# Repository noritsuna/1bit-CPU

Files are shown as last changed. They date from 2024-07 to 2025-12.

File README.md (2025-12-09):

# 1bit CPU made with ASIC (ISHI-Kai's OpenMPW PTC06-1)
[naoto64氏の1bit-CPU](https://naoto64.github.io/1bit-CPU/)を[ISHI会版OpenMPW PTC06-1](https://ishi-kai.org/openmpw/shuttle/ptc06/2024/07/06/shuttle_ISHI-Kai_OpenMPW-PTC06-1_start.html)を利用して、ASIC化しました！  
サイズは、280um x 65um くらいとなりました。元の基板が85mm x 70mmですのでおよそ36万分の1に縮小できました！  

 1bit-CPU
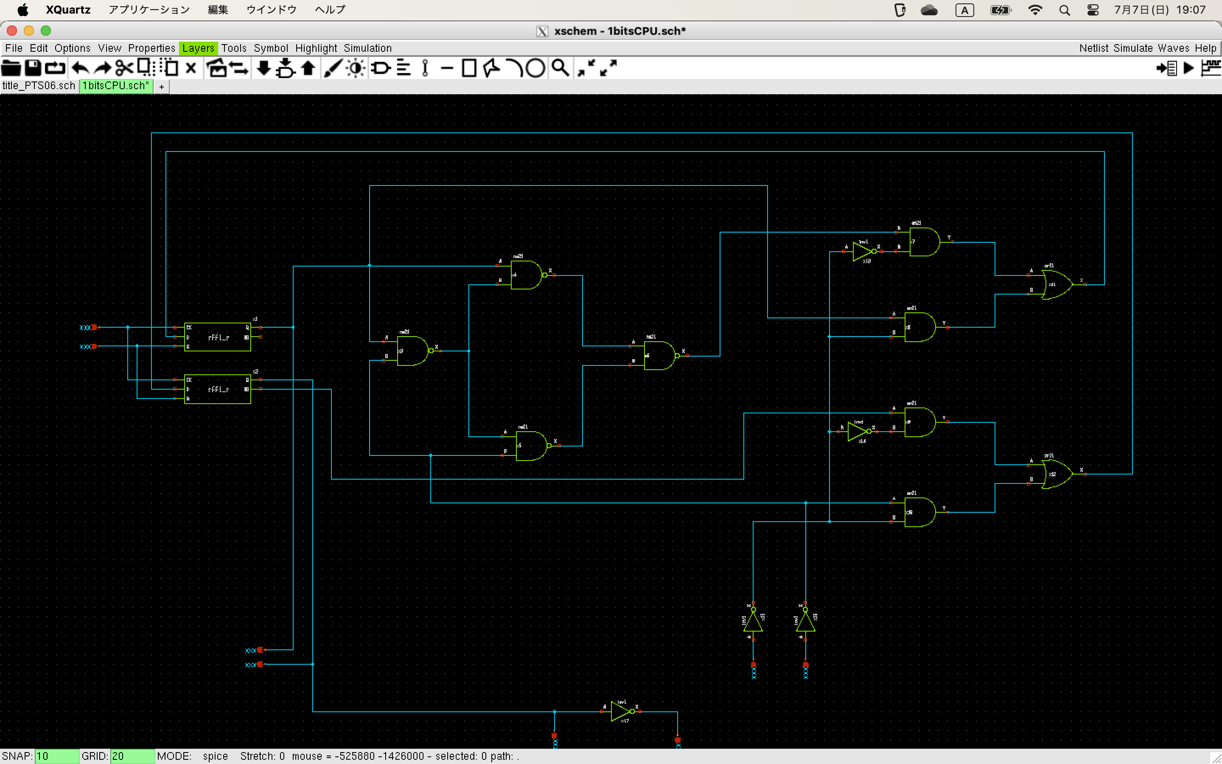
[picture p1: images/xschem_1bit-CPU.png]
1bit-CPUの回路図
 
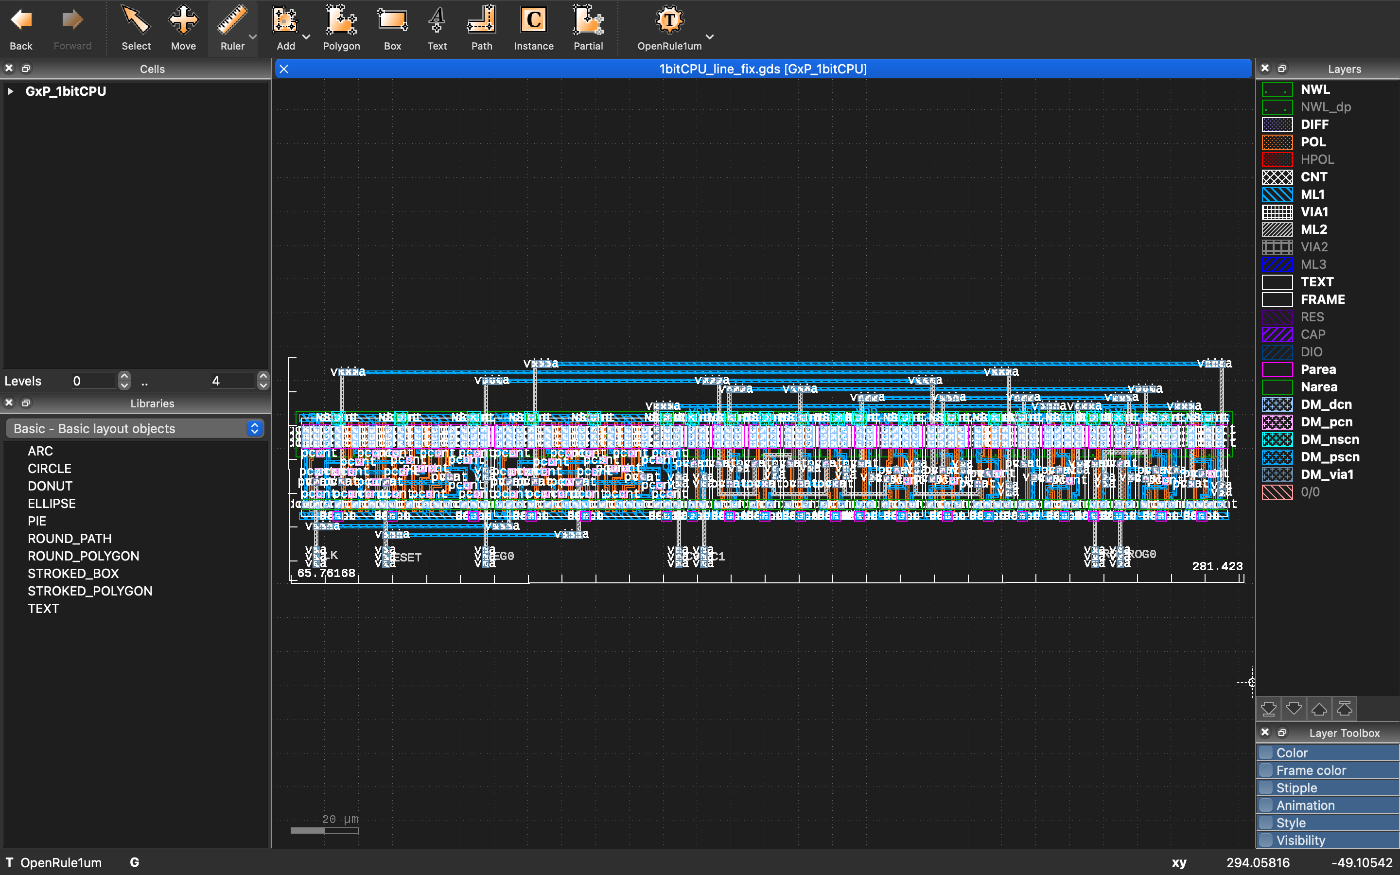
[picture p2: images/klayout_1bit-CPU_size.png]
 

# 論理回路化
まずは、74HC series logic IC部分を論理回路に起こし直して、シミュレーションを行いました。  
シミュレーションには[logicsim](http://www.cburch.com/logisim/)を利用しています。  

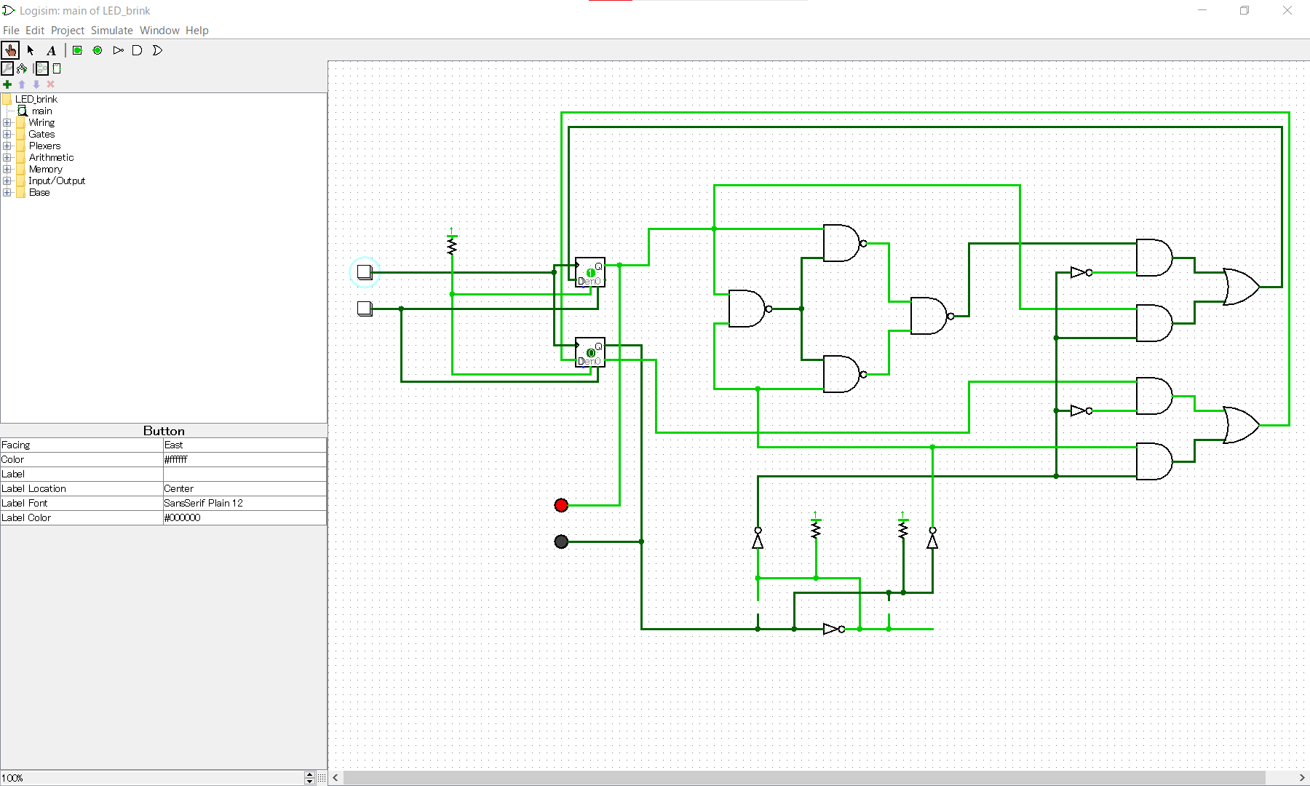
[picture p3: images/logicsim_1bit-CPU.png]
1bit-CPUのシミュレーション回路
 

## 各種回路
本家のサンプル回路をシミュレーションしました。  

-[LED点滅回路](logicsim/LED_brink.circ)
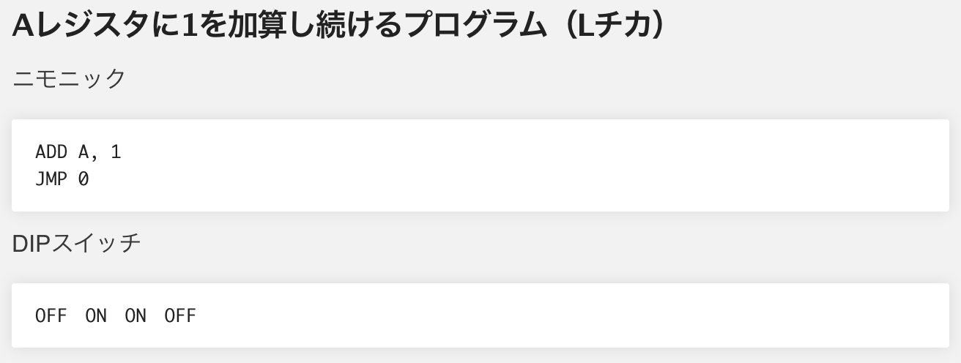
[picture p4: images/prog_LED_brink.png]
LED点滅回路
 
-[LED点灯回路](logicsim/LED_flash.circ)
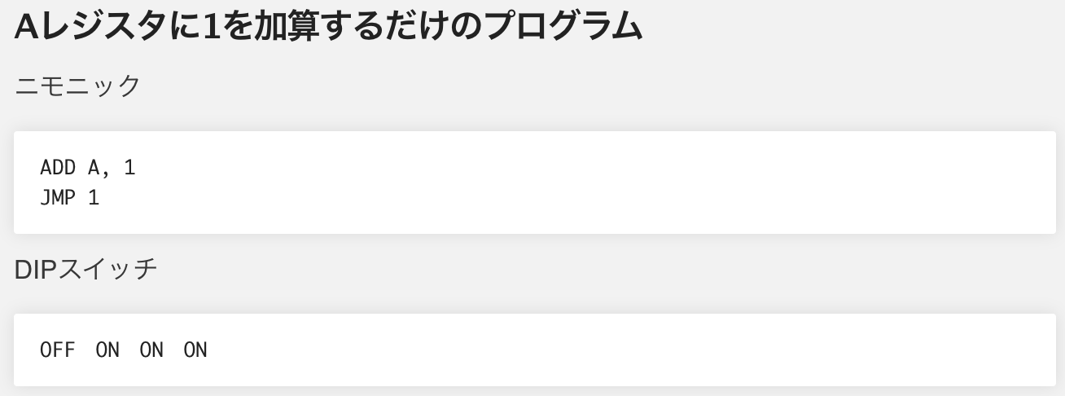
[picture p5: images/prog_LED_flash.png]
LED点灯回路
 
-[NOP回路](logicsim/NOP.circ)
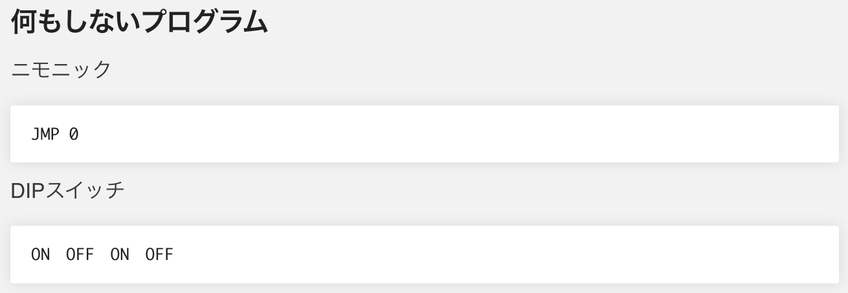
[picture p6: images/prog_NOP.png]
NOP回路
 

# AISC化
ここから、ASICにするための設計を行なっていきます。  

## 回路図
まずは、回路図を書きます。とは言っても、シミュレーション時に回路としては完成しているので、それをxschemで書き直しただけです。  

-[回路図](xschem/1bit-CPU.sch)
 1bit-CPUの回路図

## レイアウト
続いて、論理回路のレイアウトをします。  
論理回路は実際には、P-FETやN-FETを組み合わせて機能が実現されています。  

 NAND回路のFETによる実装例

もちろん、P-FETやN-FETを組み合わせて、自分で論理回路のレイアウトをしても良いのですが、通常スタセル（スタンダードセル）という物が用意されています。  
要は、P-FETやN-FETを組み合わせて作られている論理回路ライブラリです。3つ目が拡大図でP-FETとN-FETで構成されているのが確認できるかと思います。  

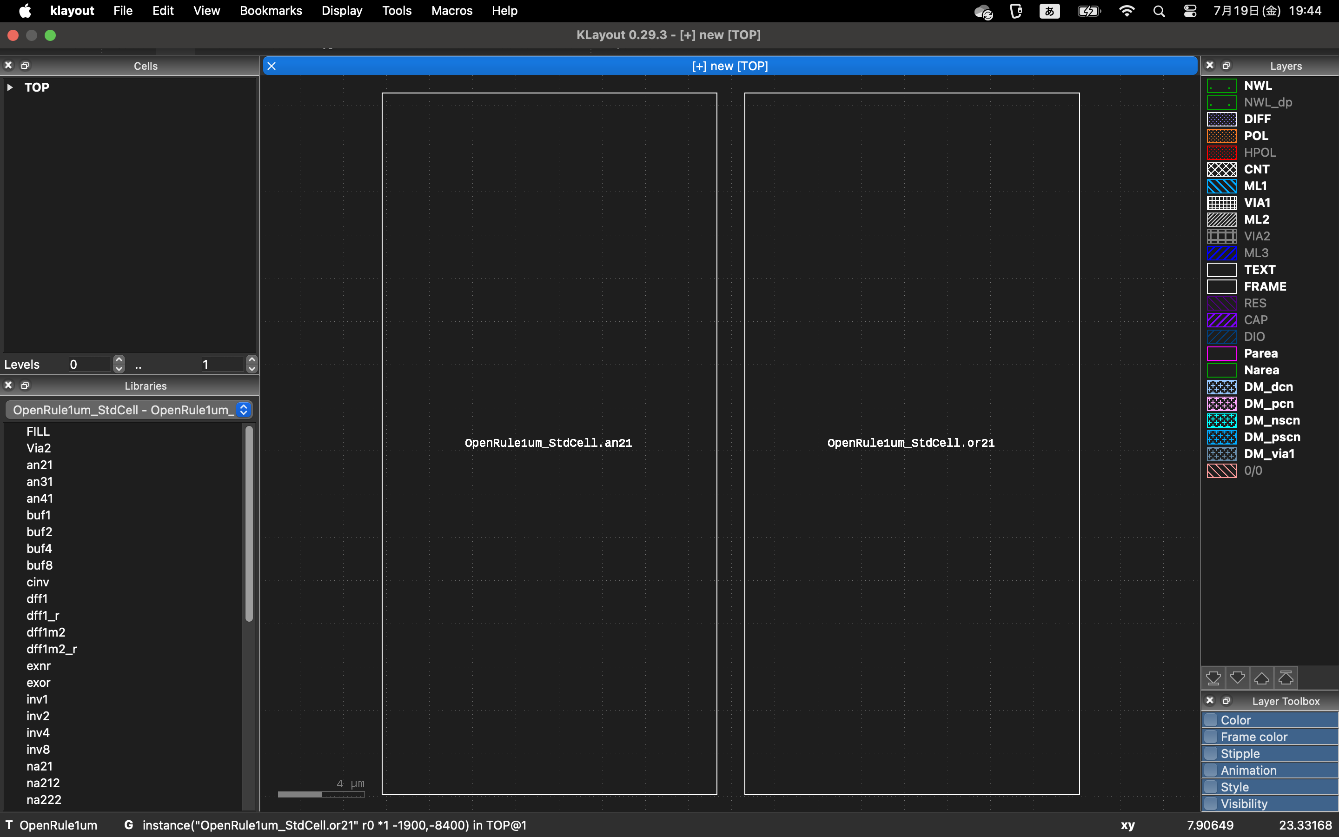
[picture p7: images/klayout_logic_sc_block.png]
スタセル
 
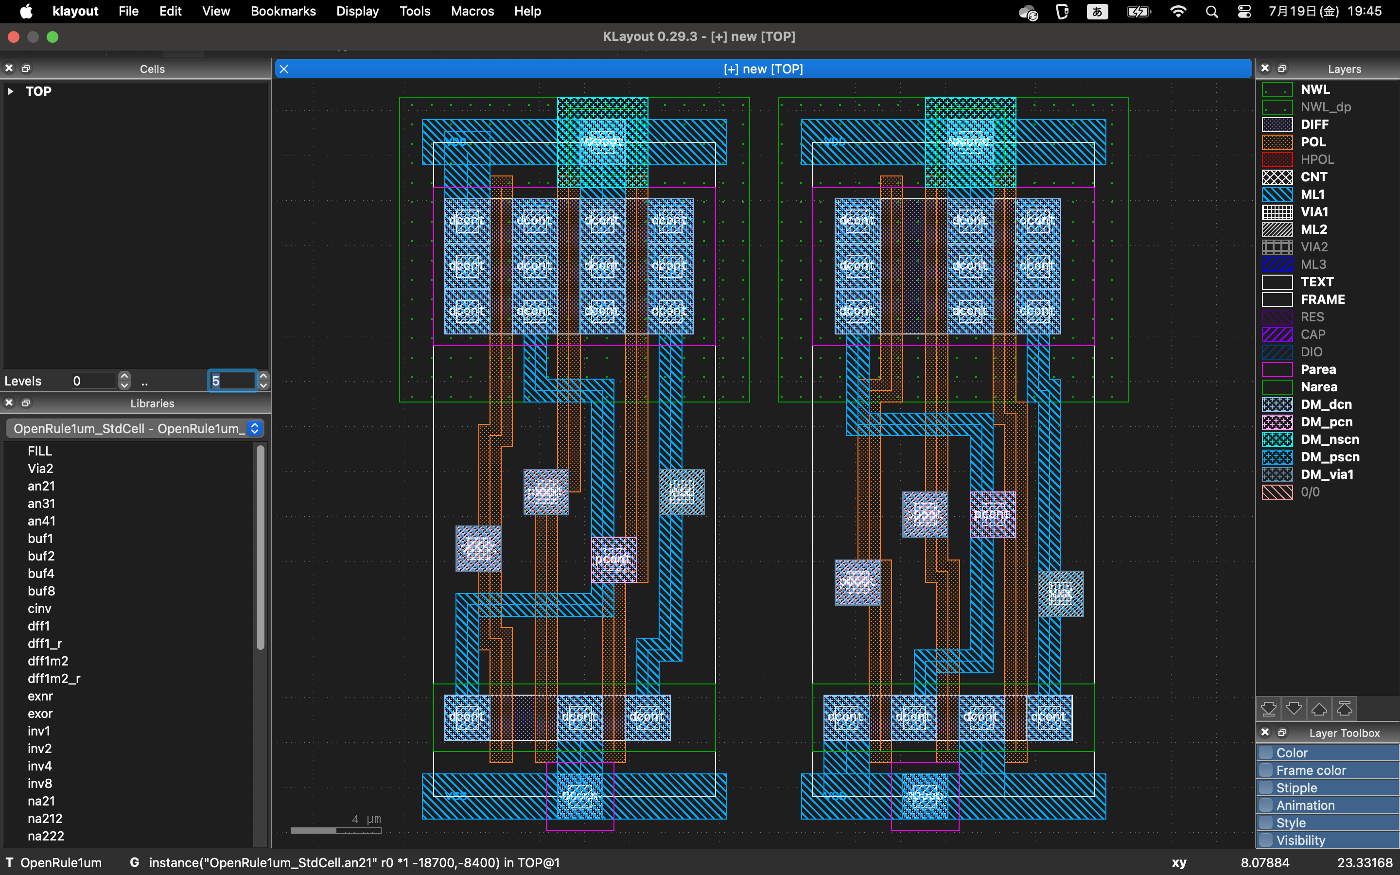
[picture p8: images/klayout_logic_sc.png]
スタセルの中身
 
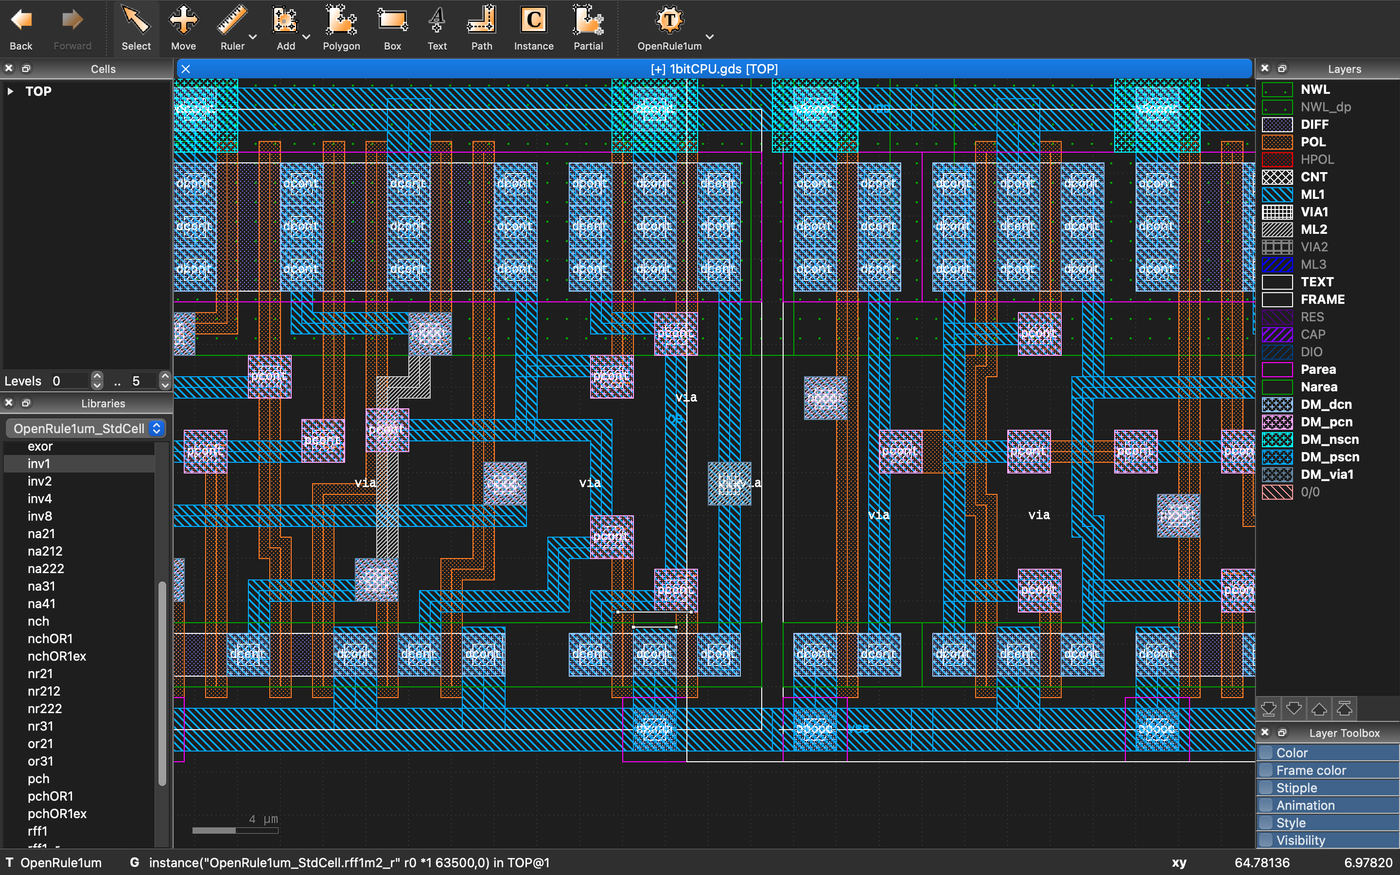
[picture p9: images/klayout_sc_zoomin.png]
スタセル拡大
 

回路図そのままで、スタセルを配置してみたパターンです。  

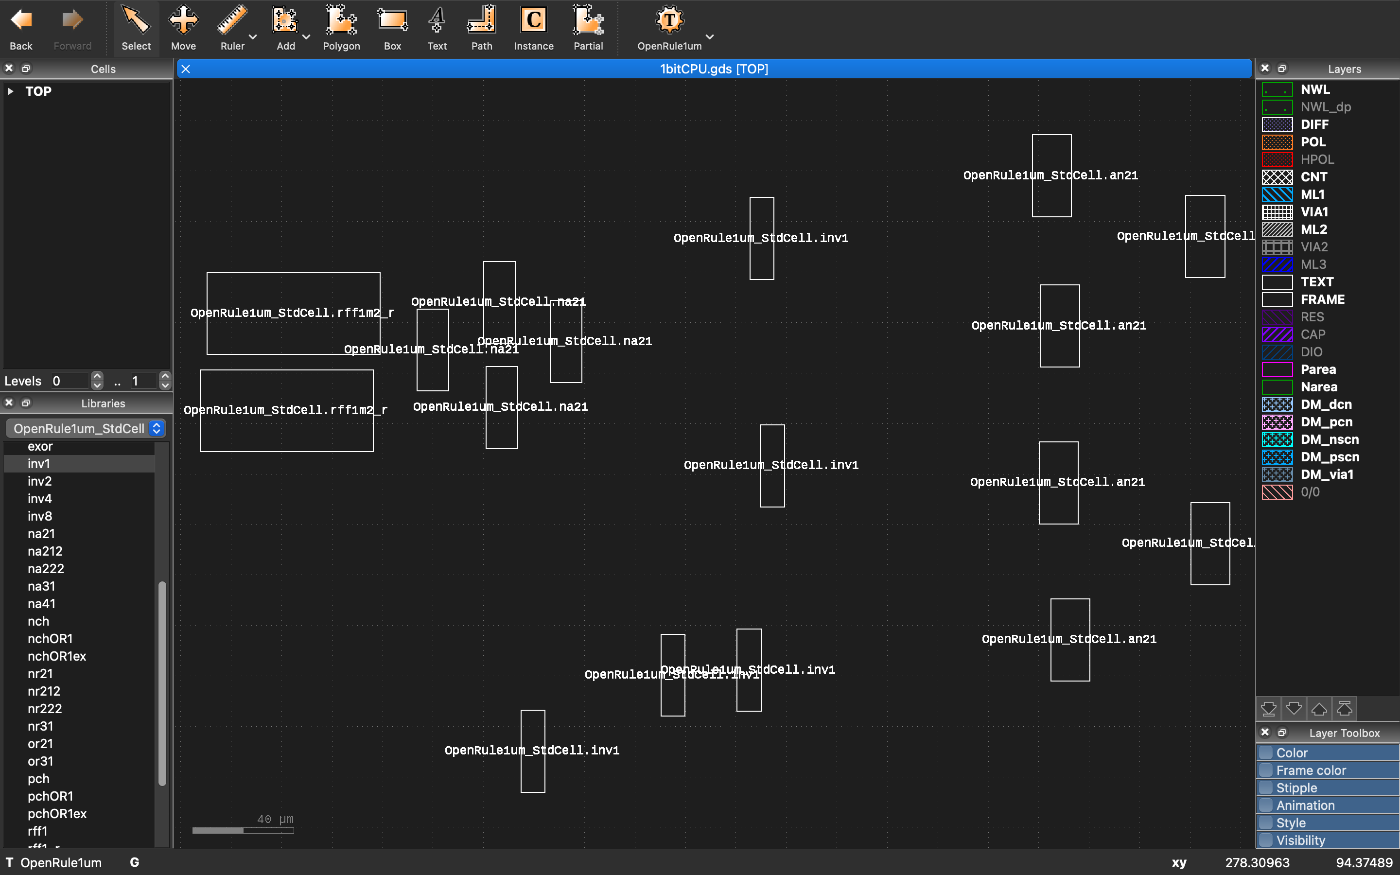
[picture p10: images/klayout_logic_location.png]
回路図のままの配置
 

### 一列化
このまま配線するだけでも良いのですが、通常のスタセルはVerilogなどから自動的にレイアウトに変換する時に使用するように作成されています。  
そのため、スタセルは自動レイアウトを考慮して、下の図のように縦の長さが固定されて、上部にVDDがあり下部にVSS(GND)があるタイル状の形状をしています。これらを横に並べて利用することで、VSSやVSSが接続されて、自動ルーティングや配置がしやすいように作られています。  

 スタセルの中身

そのため、人間が見やすい回路図の形で配置し、配線すると無駄が多くなります。  
そこで、回路図をこのタイル型レイアウトに合わせて、一列に並ぶように書き換えます。  
（通常は、この手の論理回路で設計するロジック回路を手でレイアウトすることはあまり無いと思いますので、今回は結構特殊なシチュエーションとなります。）  

-[1ライン化回路図](xschem/1bit-CPU_1line.sch)
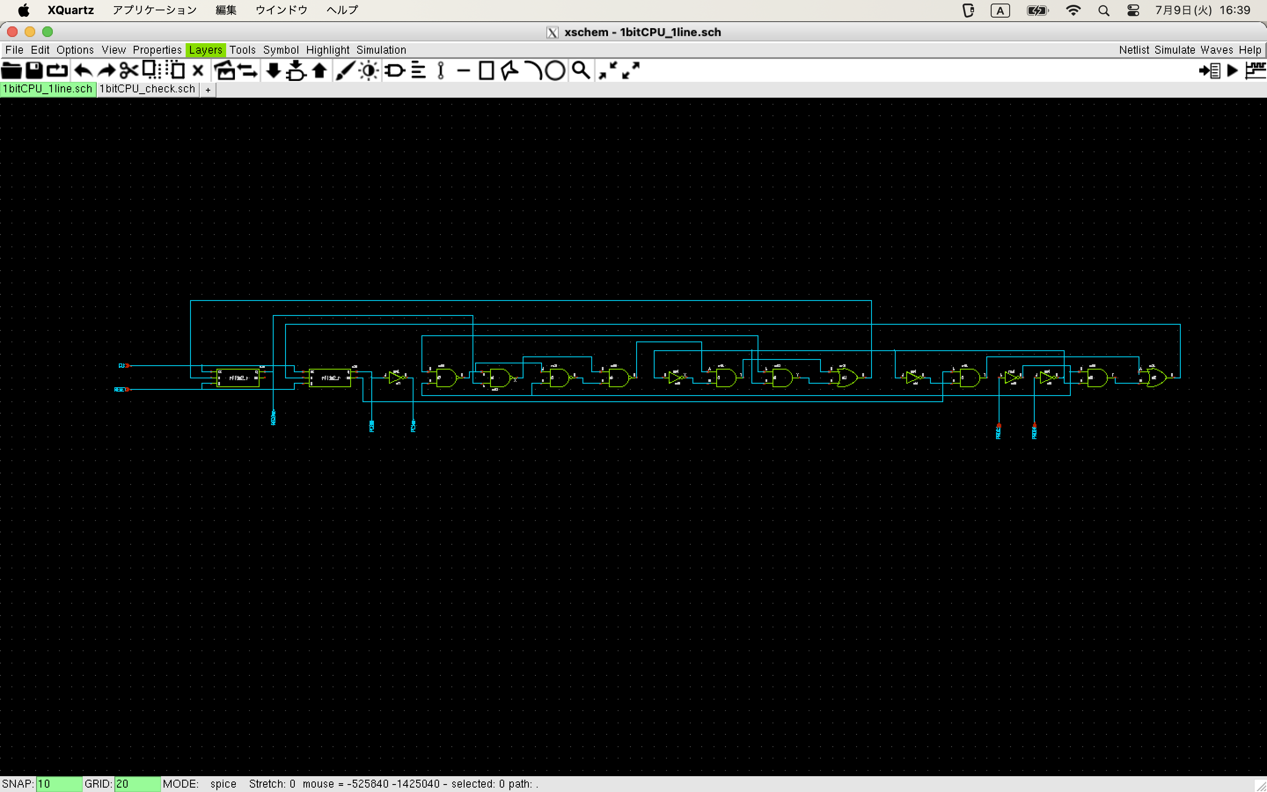
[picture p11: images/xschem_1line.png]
回路図の1ライン化
 
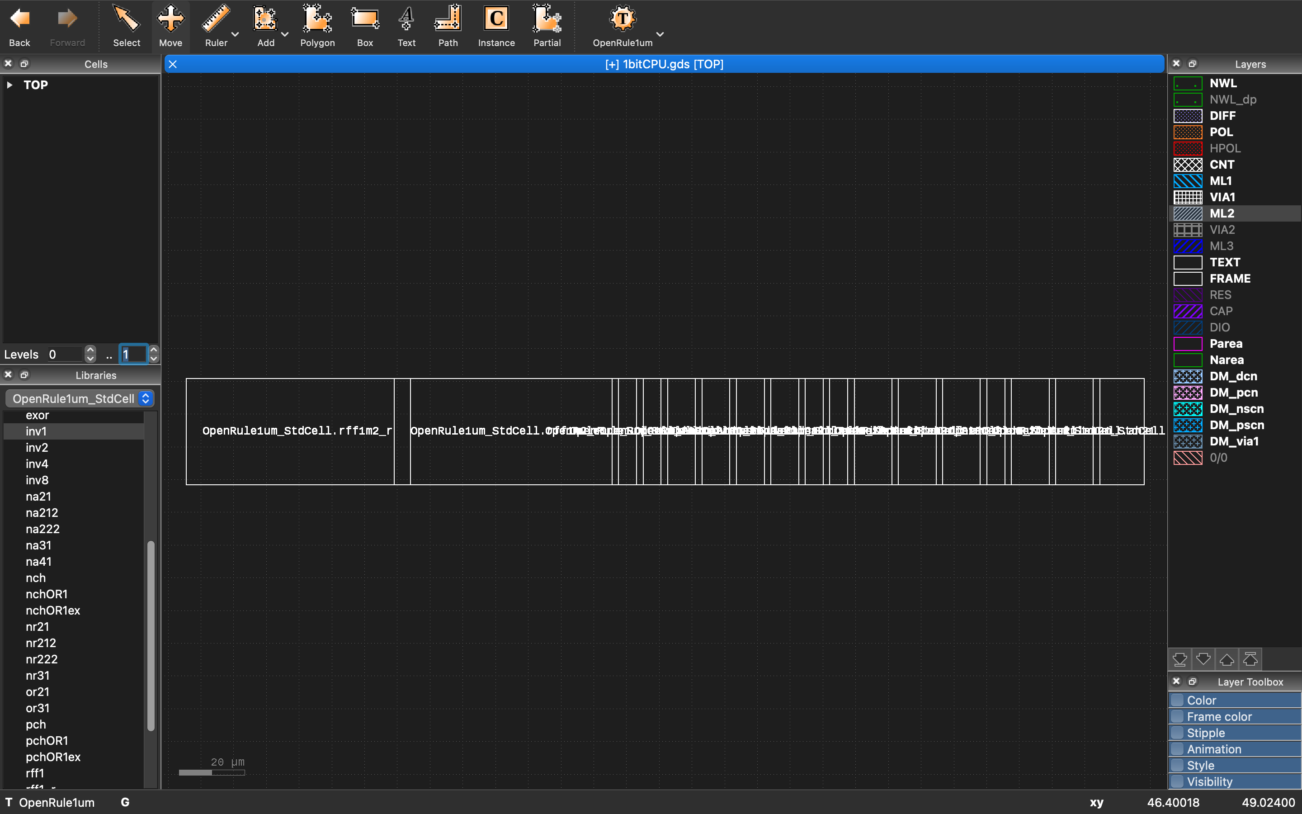
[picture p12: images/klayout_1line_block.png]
レイアウトの1ライン化
 
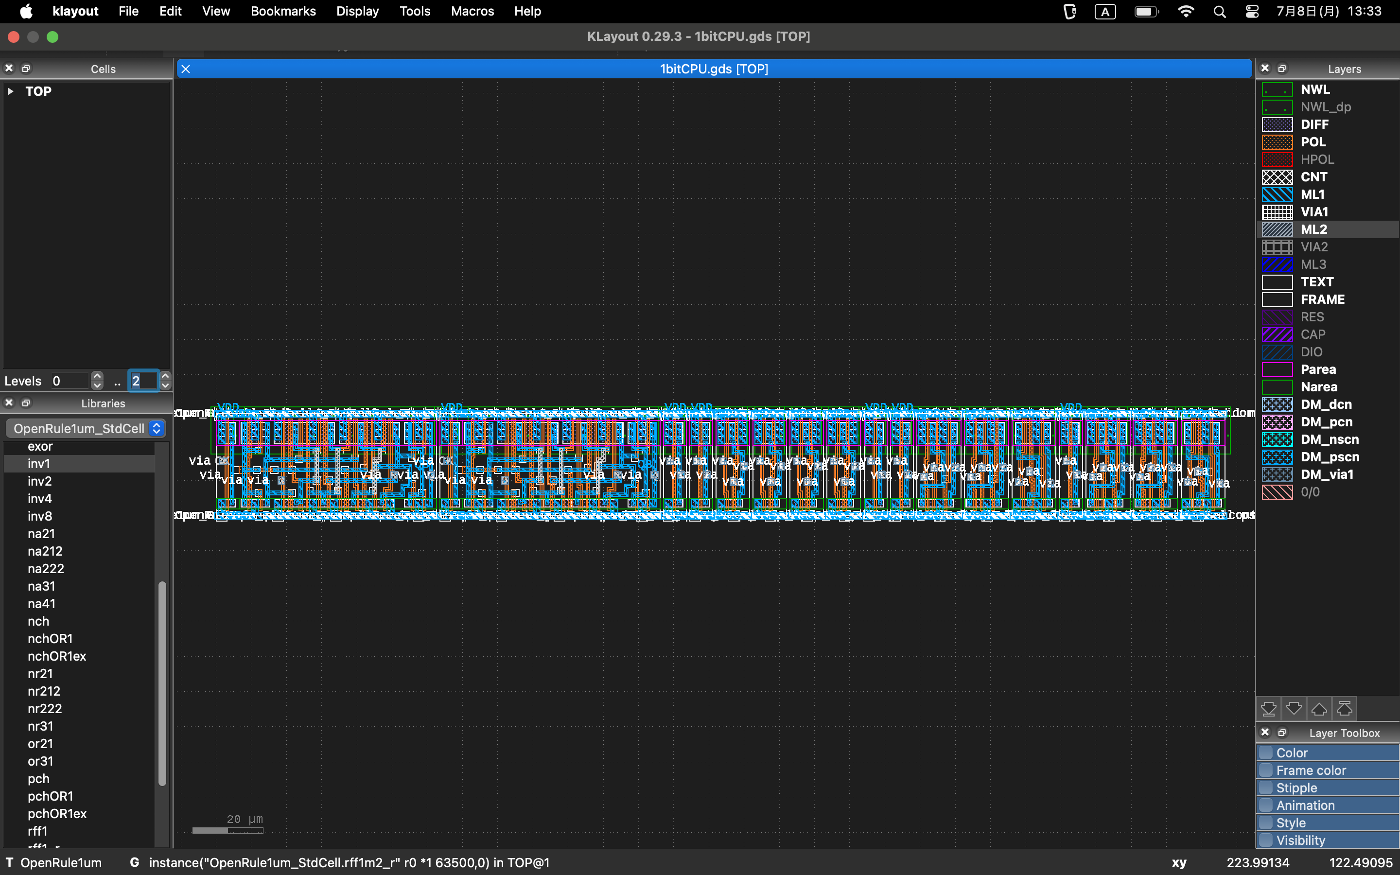
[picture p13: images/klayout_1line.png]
レイアウトの1ライン化の中身
 

### 最終レイアウト
一列化して、配線したレイアウトです。  

-[レイアウト](klayout/1bit-CPU.gds)
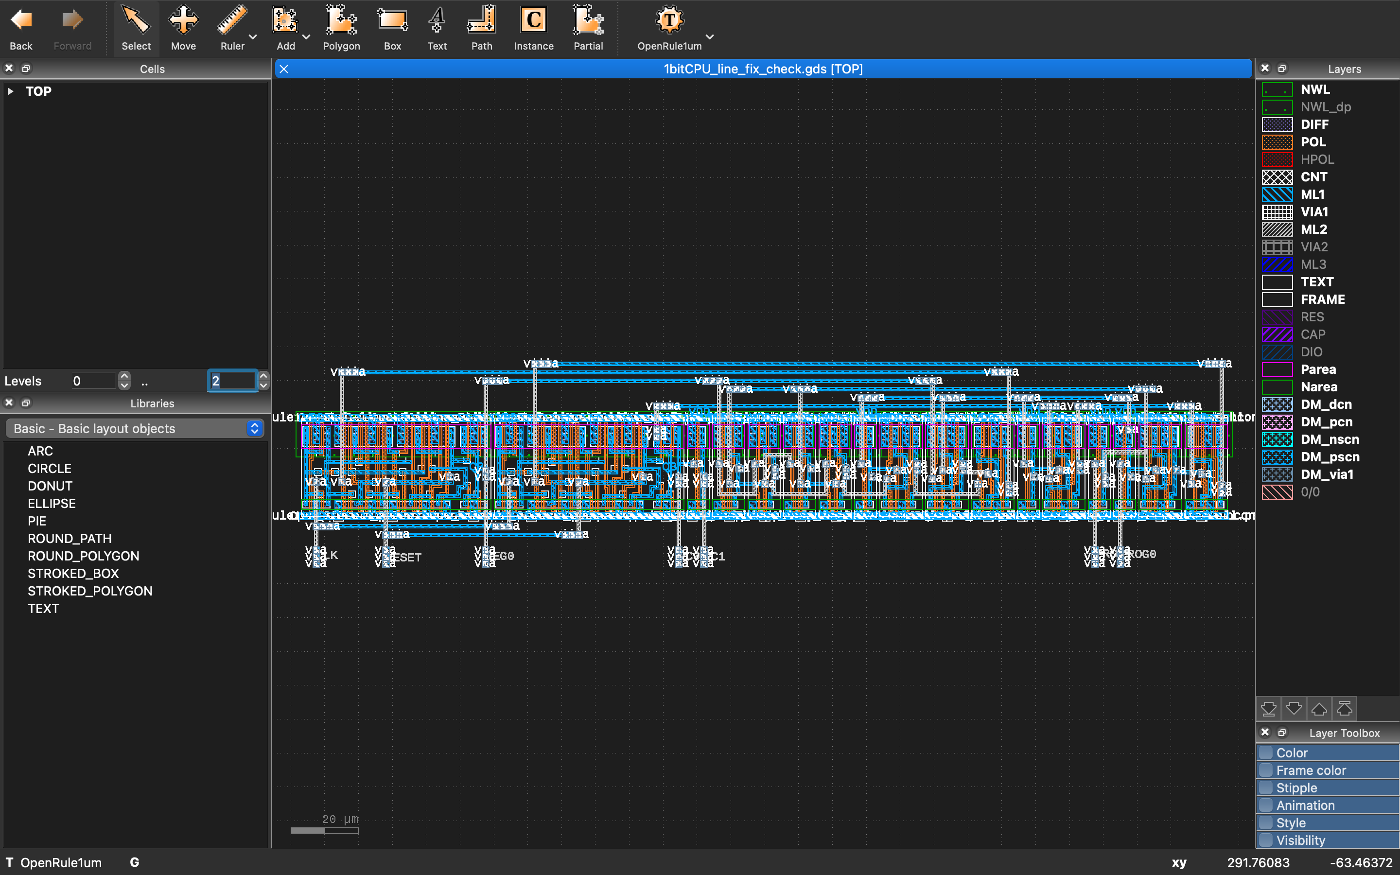
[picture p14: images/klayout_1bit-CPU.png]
 

## LVS
手配線のため回路図とレイアウトが間違っている可能性があるため、LVS（Layout vs Schematic）をかけるのですが、OpenRule1umのスタセルの作りが微妙のため、完全体とはなりませんでした。  
そのため、目LVSで乗り切りました。とは言っても、接続先は下の図（LVSの配線ハイライト）のように強調表示されるためそれほど大変ではありません。  

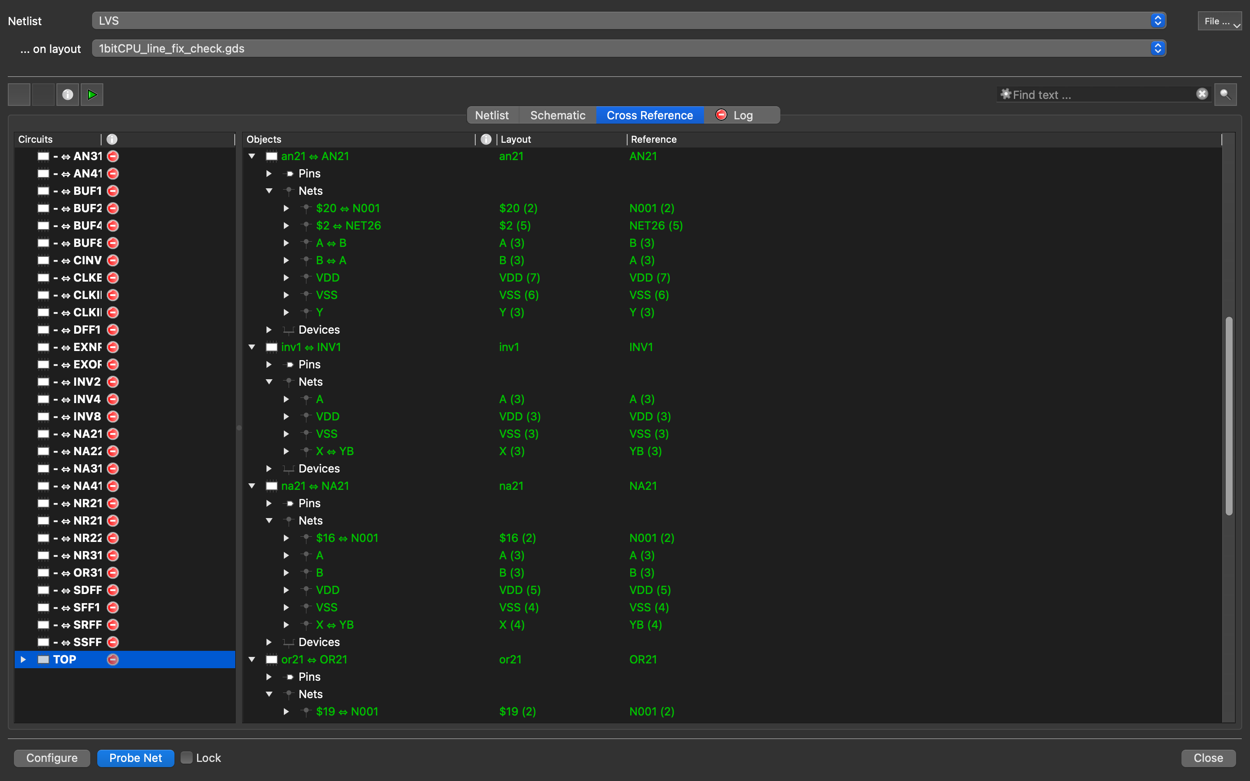
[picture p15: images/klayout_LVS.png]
1bit-CPUのLVS
 
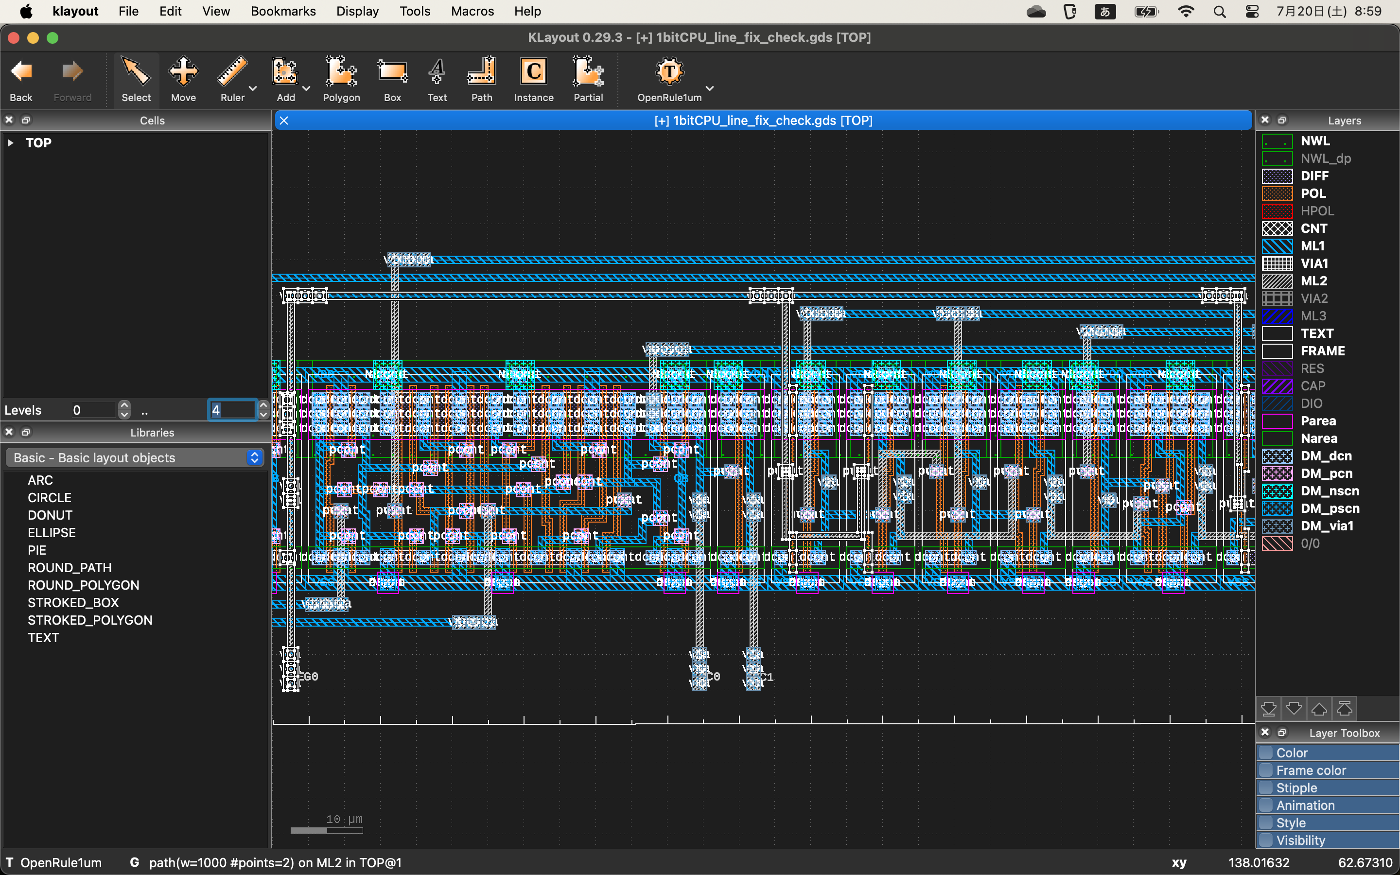
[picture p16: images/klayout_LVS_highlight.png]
LVSの配線ハイライト
 

## パッドへの接続
最後に、実際の半導体上のパッド（ピン）に各ポートを接続します。  
本来ならピンの設定（INやOUT、デジタルかアナログかなどを指定する）があるのですが、そこの設定はNDAの範囲内での設定となるため、ここでは行いません。そのため、これは実質的に仮配線となります。  

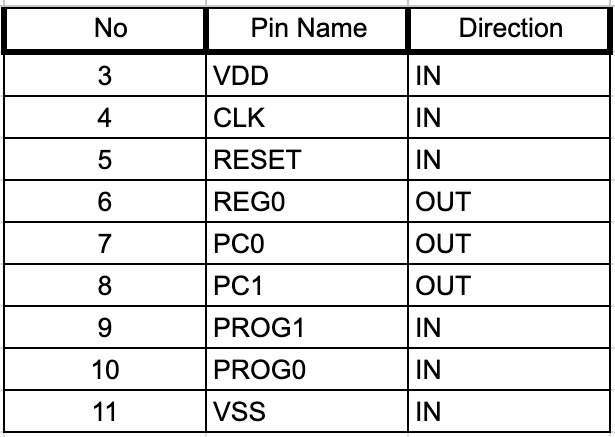
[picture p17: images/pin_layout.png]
1bit-CPUのピンレイアウト
 

-[パッド付きレイアウト](klayout/1bit-CPU_frame.gds)
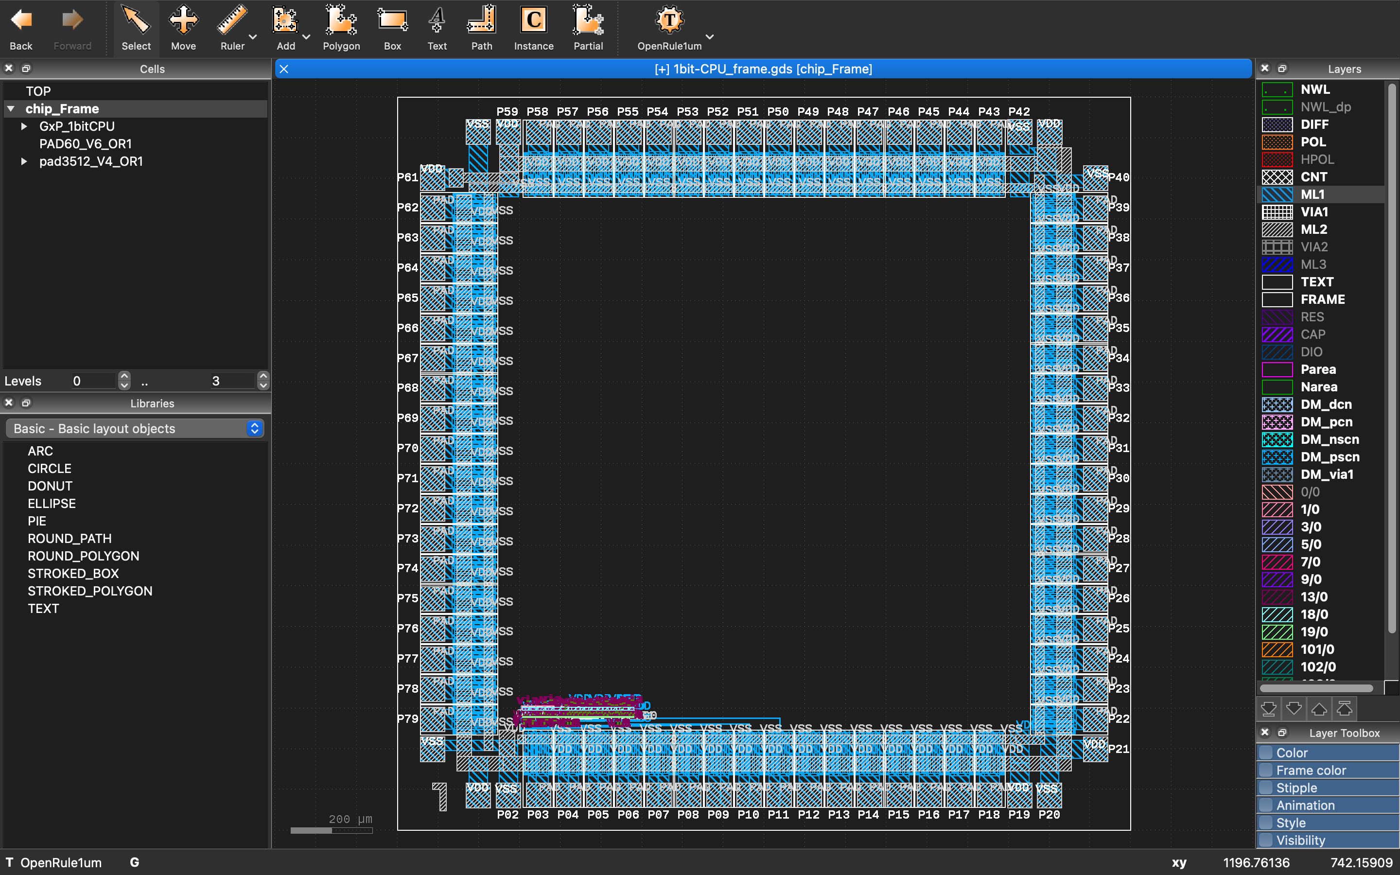
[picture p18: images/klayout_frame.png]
パッドフレーム付き
 
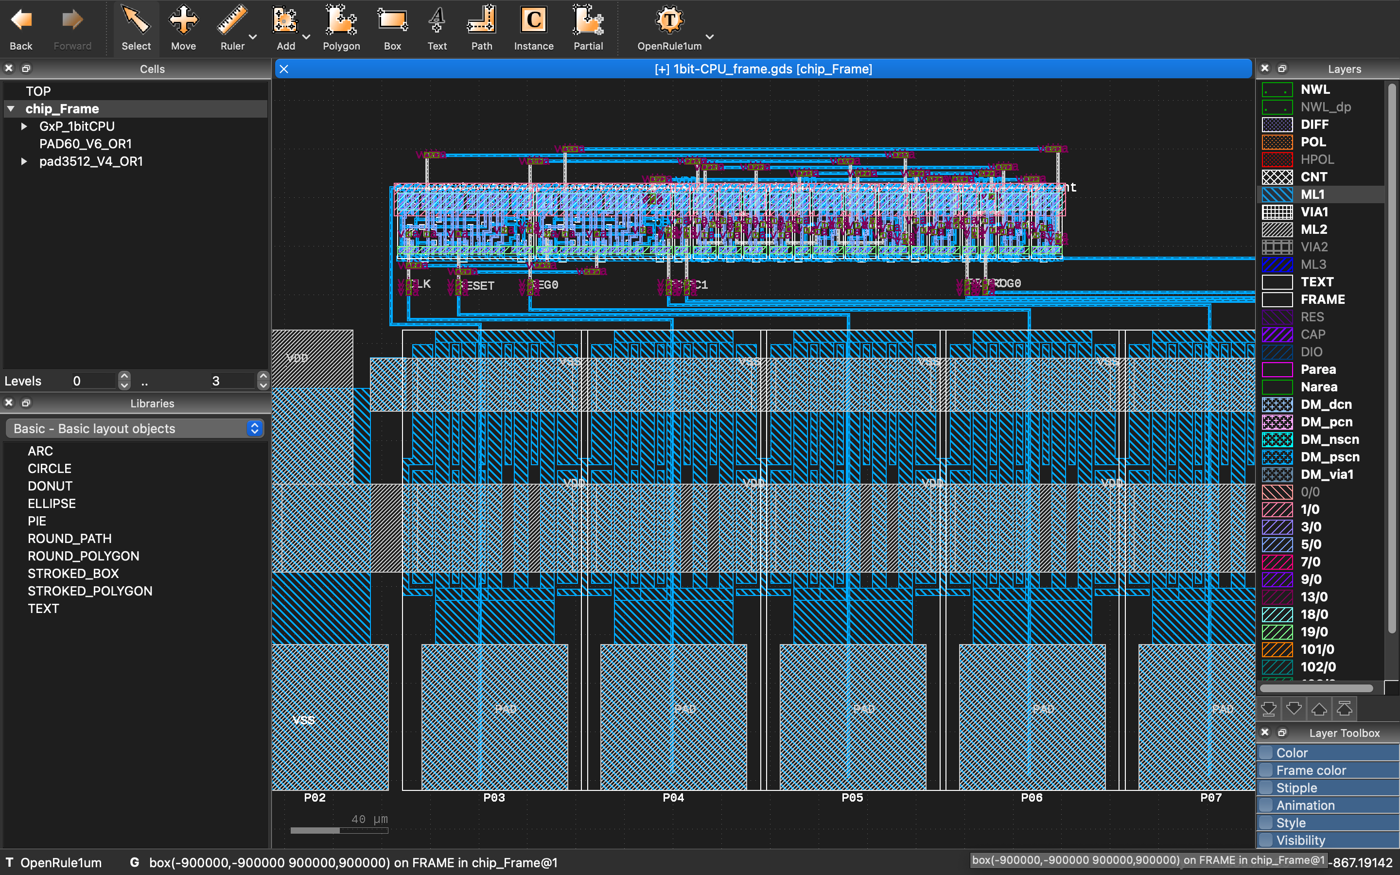
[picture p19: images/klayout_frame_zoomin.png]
パッドフレーム拡大
 

## WSL Image
上記の回路図やシミュレーション、レイアウト、DRC、LVSを実行するための環境をセットアップしたWSLイメージを用意しています。

- [WSL Image](https://www.noritsuna.jp/download/ubuntu2204_PTC06-1.tar.xz)
    - ID: ishikai
    - Pass: ishikai

### Installing WSL Images
`wsl --import-in-place ubuntu2204_PTC06-1 .\ubuntu2204_PTC06-1\ext4.vhdx`

起動には"ubuntu2204_PTC06-1.lnk"をご利用ください。  

### Deleting WSL Images
イメージも削除されるので注意してください。    

`wsl --unregister ubuntu2204_PTC06-1`

# [本チップ用ボード](kicad/1bit-CPU_board)
メモリや外部クロック、動作確認用のLEDを搭載したボードをKiCADで設計しました。  

[本チップ用ボードディレクトリ：KiCADファイル](kicad/1bit-CPU_board)

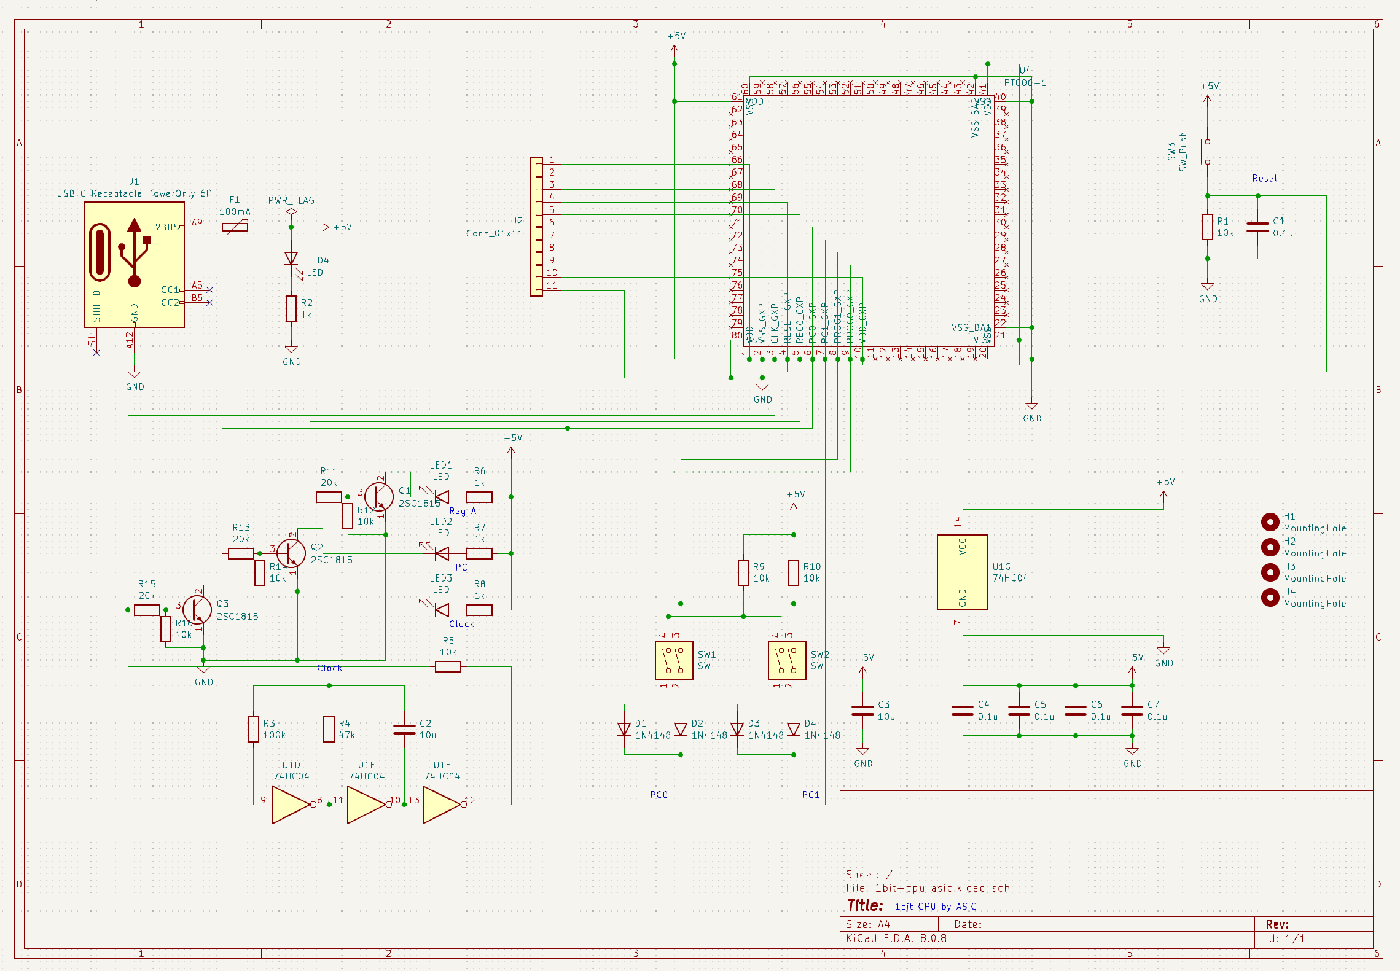
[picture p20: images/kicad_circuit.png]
 
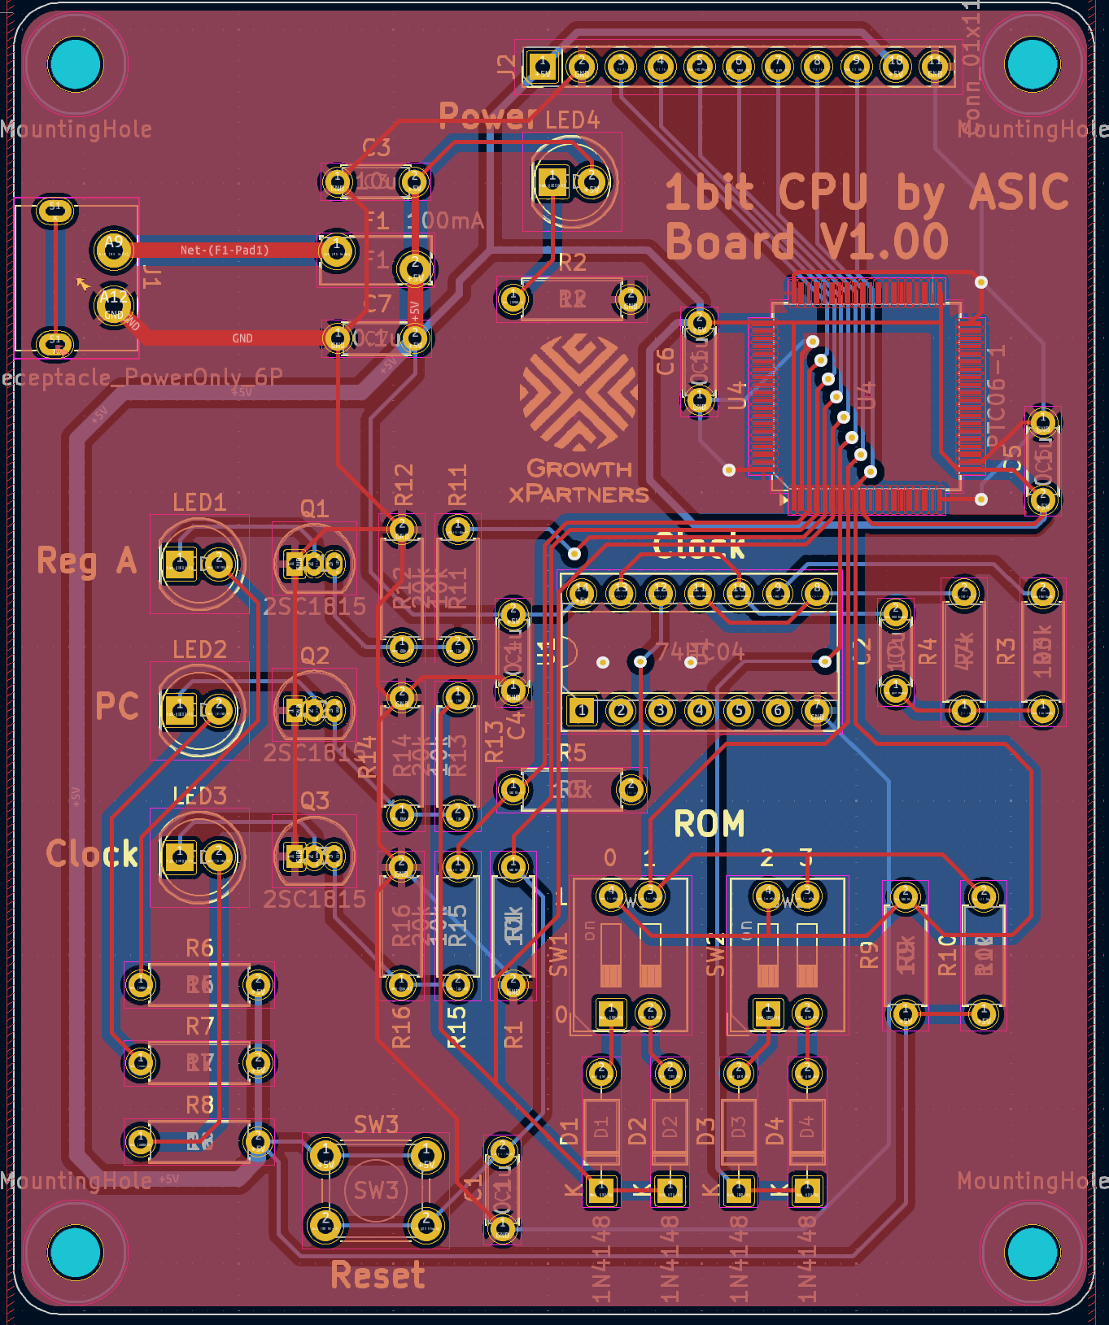
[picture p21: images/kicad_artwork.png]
 

## 動作確認
ボードが到着したので、部品を実装して動作確認しました。  
無事に、本家の1bit-CPUボードと同じ動きをしております！  
※クロックが微妙にずれているため、同期はしてません。

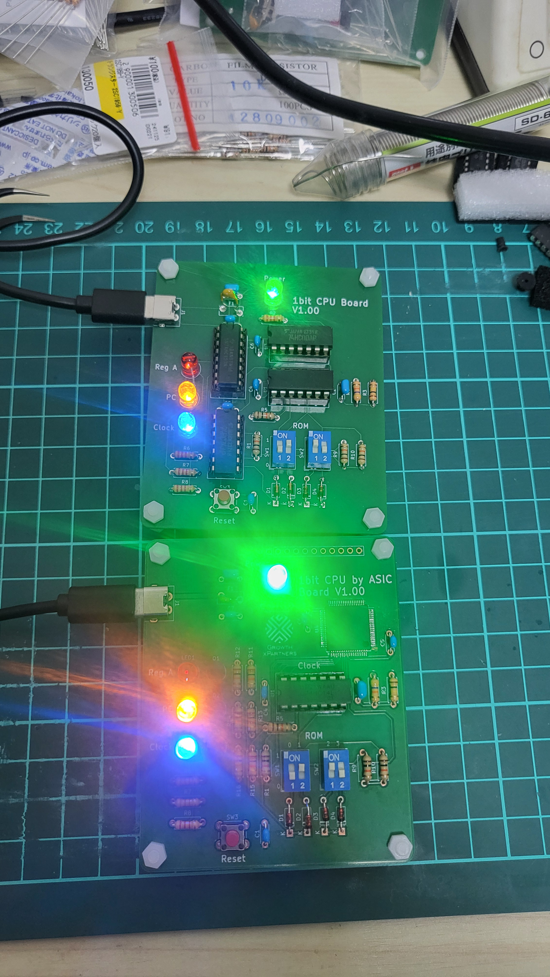
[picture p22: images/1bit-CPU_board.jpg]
ボード：実物
 
[ボード：YouTube動画](https://youtube.com/shorts/-G9ZElhzAAo?feature=share)
[ボード：動画ファイル](images/1bit-CPU_board.mp4)

# [本チップ用ラズパイHAT](kicad/1bit-CPU_HAT)
ラズパイHATをKiCADで設計しました。  
ただ、本CPUは5V動作で、ラズパイは3.3V動作のため、レベル変換が必要となります。  

## インバータの応用
レベル変換の一つの手として、バッファ回路を使う手があります。  
バッファ回路＝インバータ回路*2です。そこで、今回は、みんなで実装したインバータ回路をそのまま使うことにしました。  

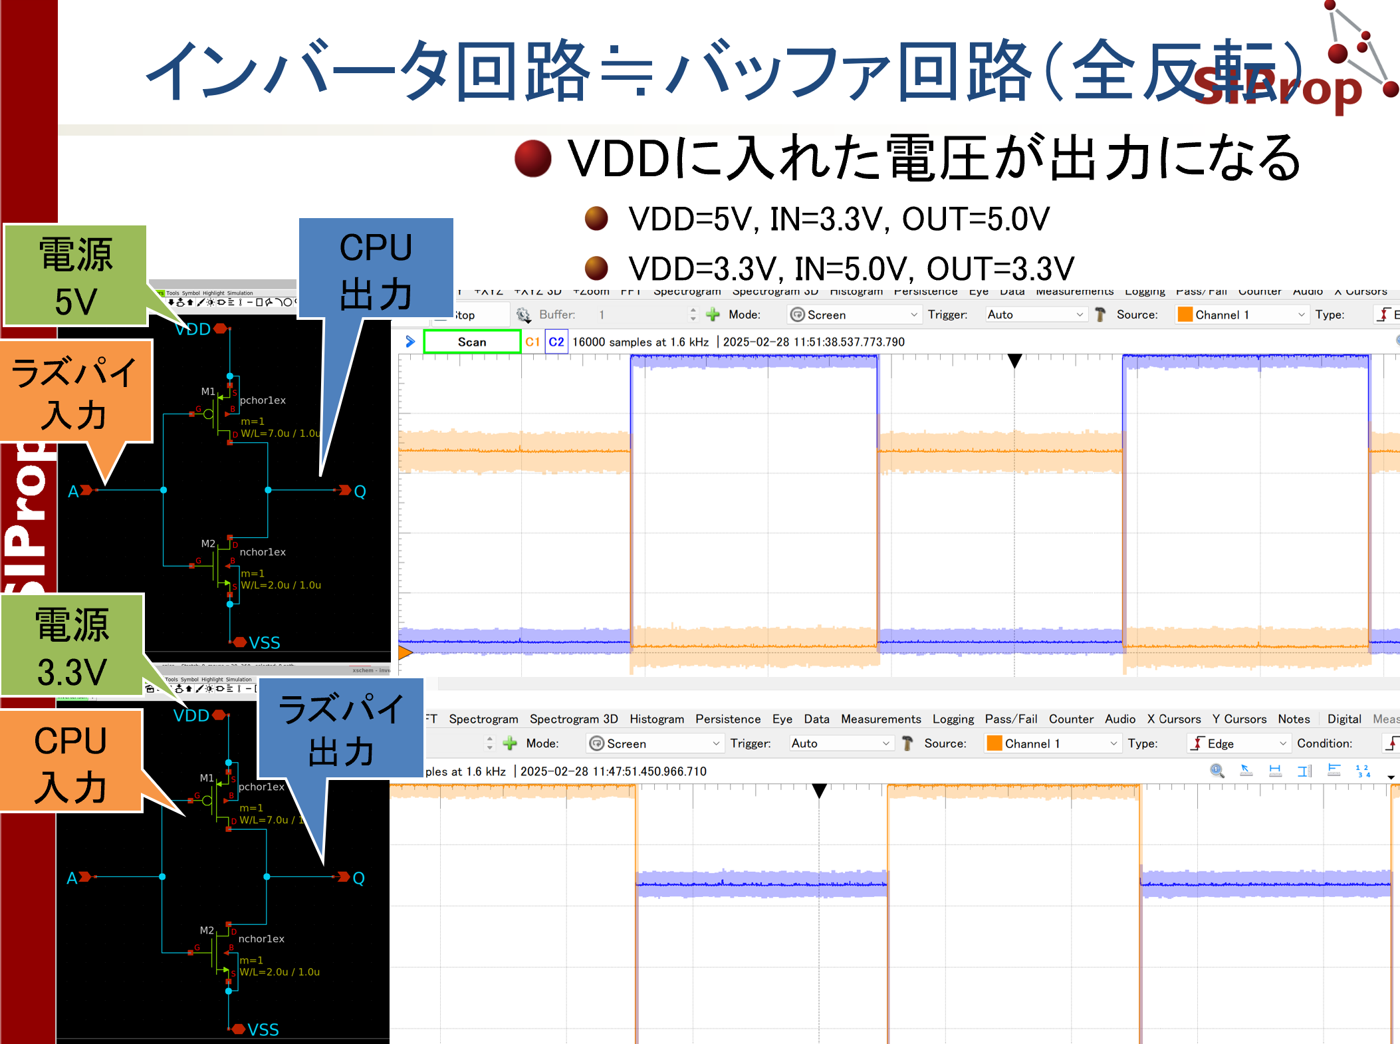
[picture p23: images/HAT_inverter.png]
インバータ動作図
 
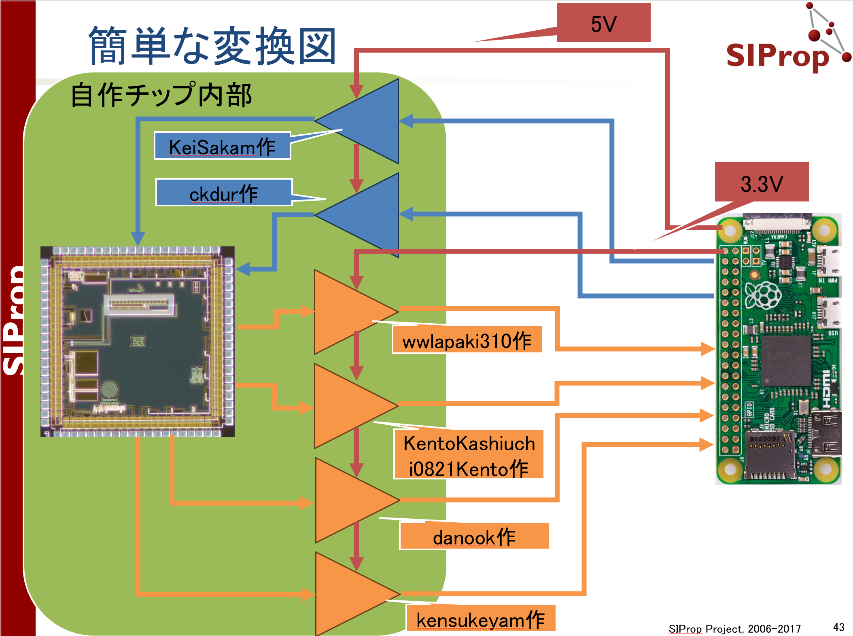
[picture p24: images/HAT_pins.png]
インバータの接続図
 
 みんなのインバータ

### インバータの動作確認
- [インバータ動作チェック用AD3設定ファイル](kicad/1bit-CPU_HAT/Inverter_checker.dwf3work)

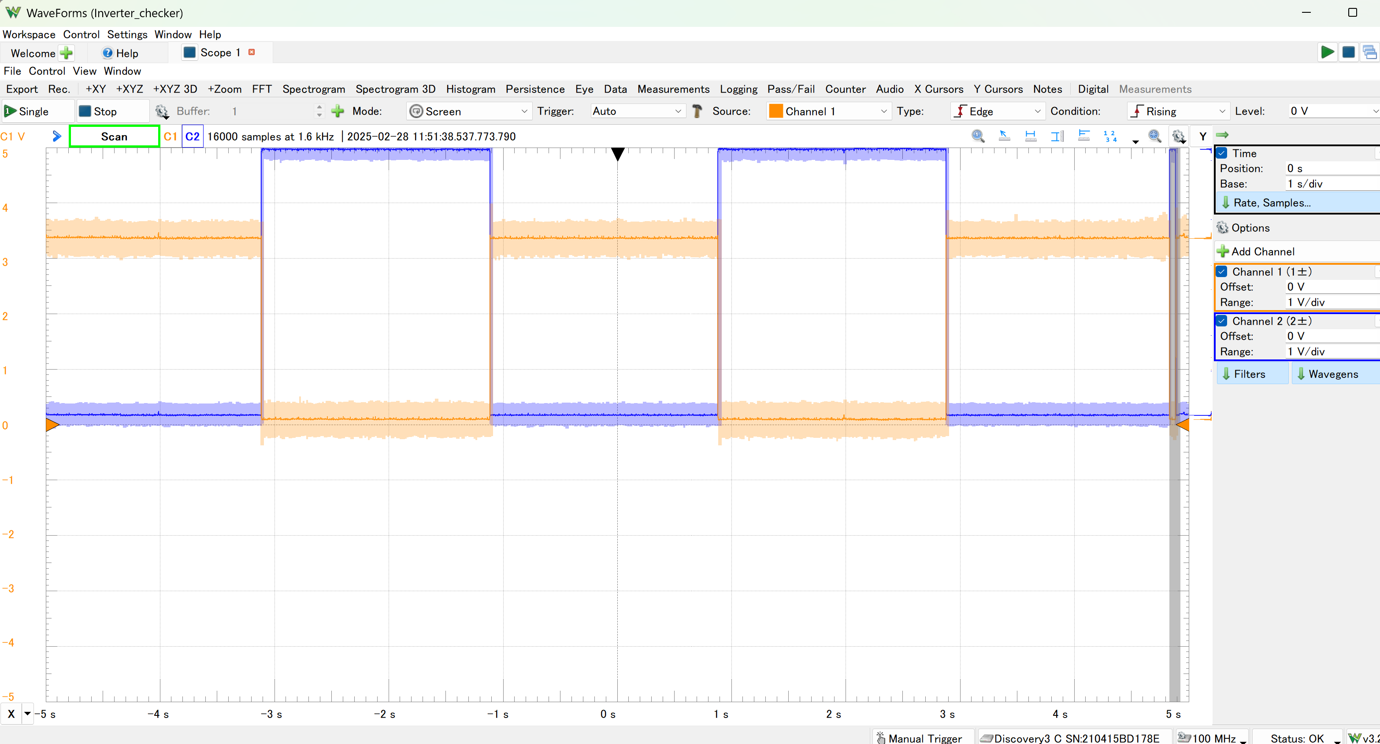
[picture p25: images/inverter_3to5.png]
インバータのバッファ動作 3.3V->5V
 
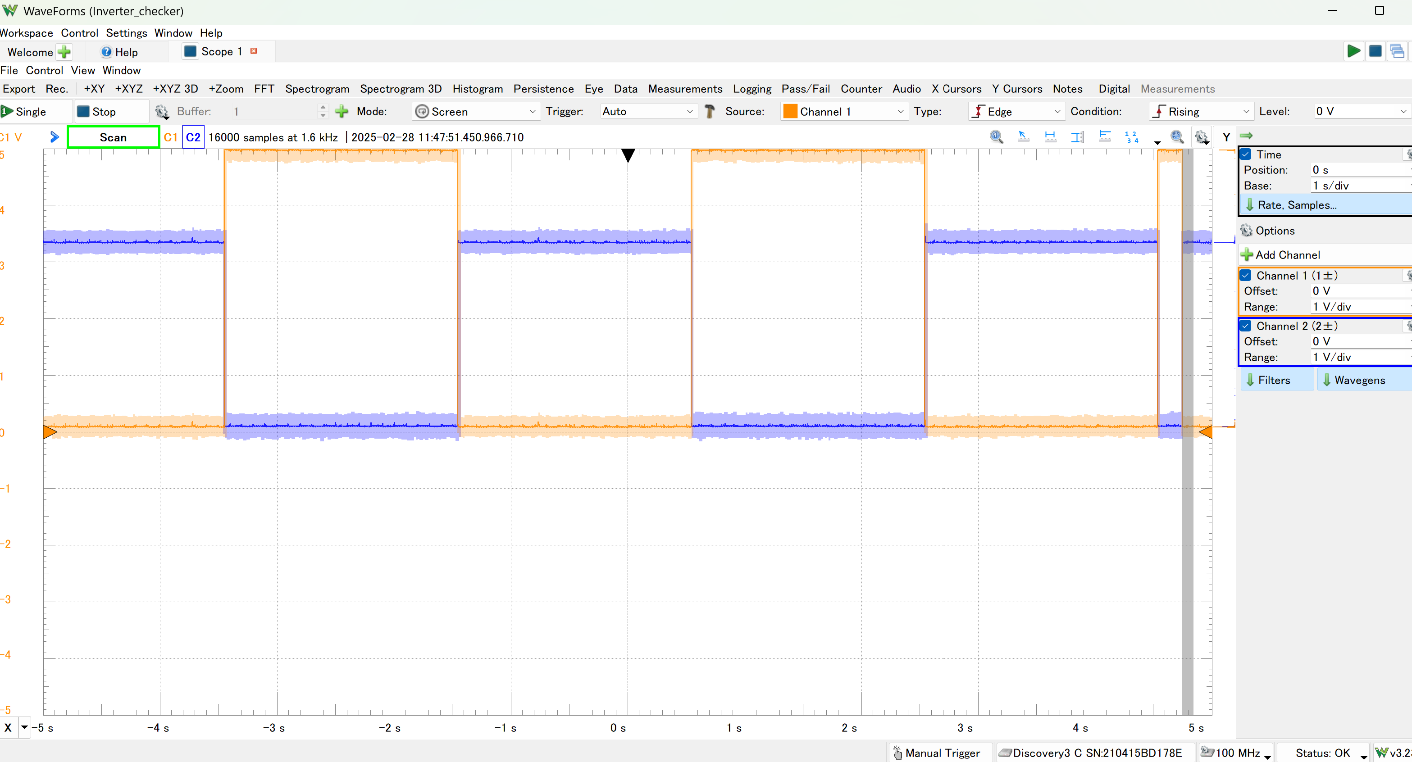
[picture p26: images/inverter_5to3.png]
インバータのバッファ動作 5V->3.3V
 

## クロック源
クロック源として、りょうすさんが実装したVCOを流用しました。  

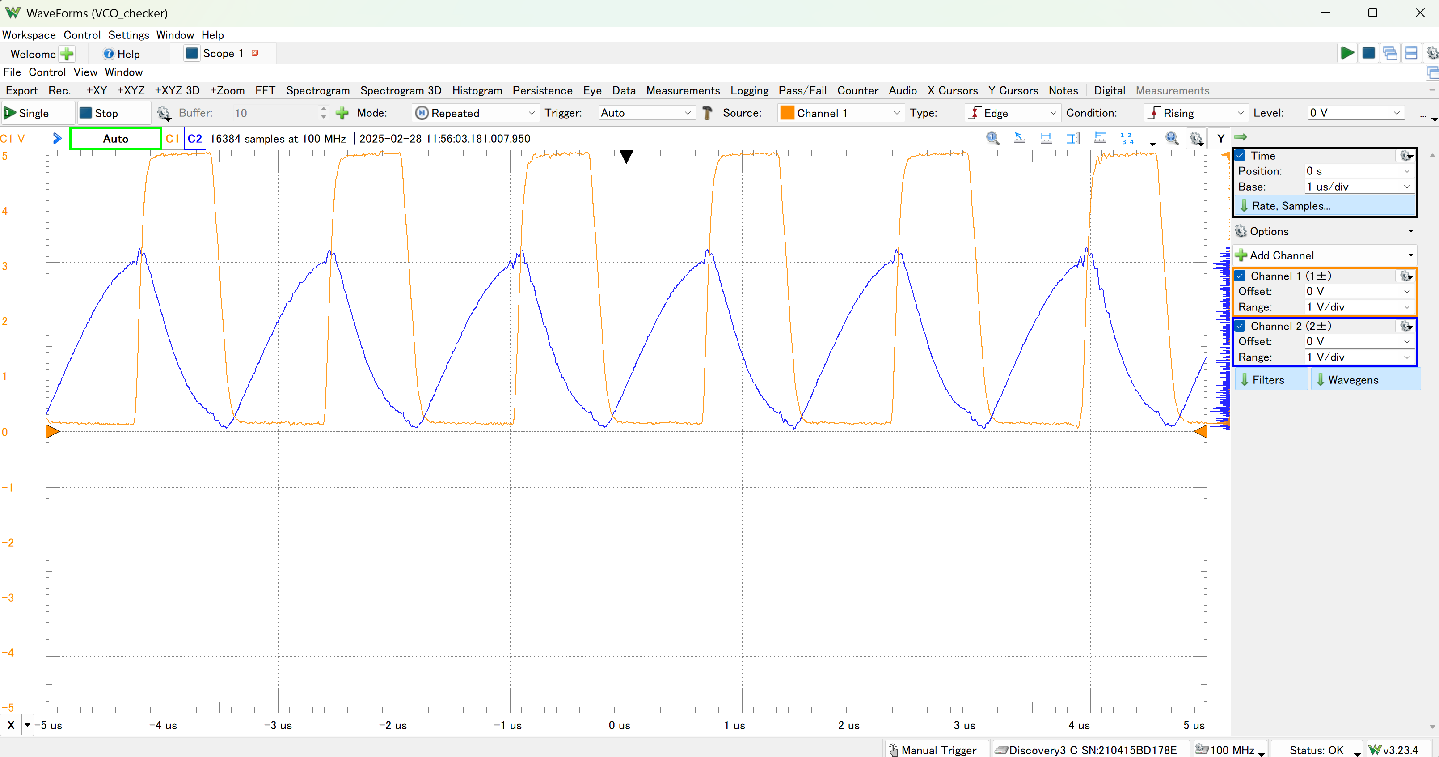
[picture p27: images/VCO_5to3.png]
VCOの動作
 

### クロック源の動作確認
- [VCO動作チェック用AD3設定ファイル](kicad/1bit-CPU_HAT/VCO_checker.dwf3work)
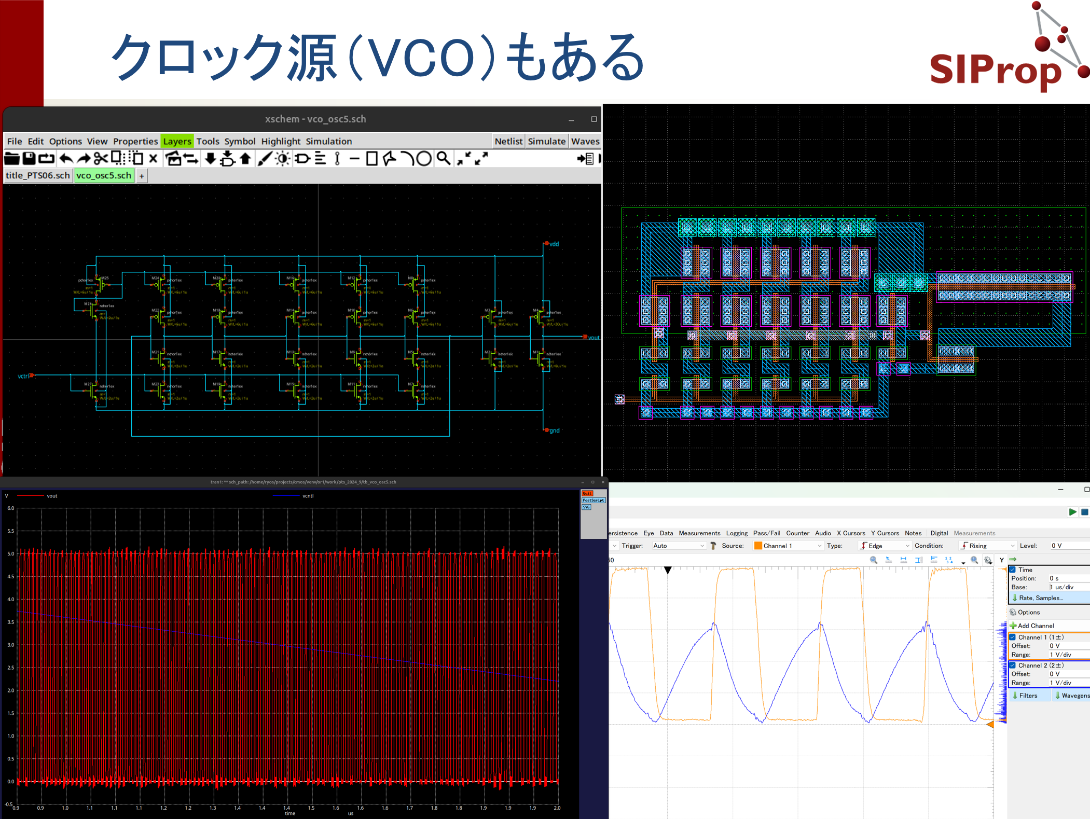
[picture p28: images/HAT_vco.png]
VCOの動作図
 

## HATの実装
チップ内にあるインバータ回路やVCOを利用したため、外部回路は3つのみとなっています。  

- LED点灯用回路
- リセット回路
- VCO用電圧制御回路

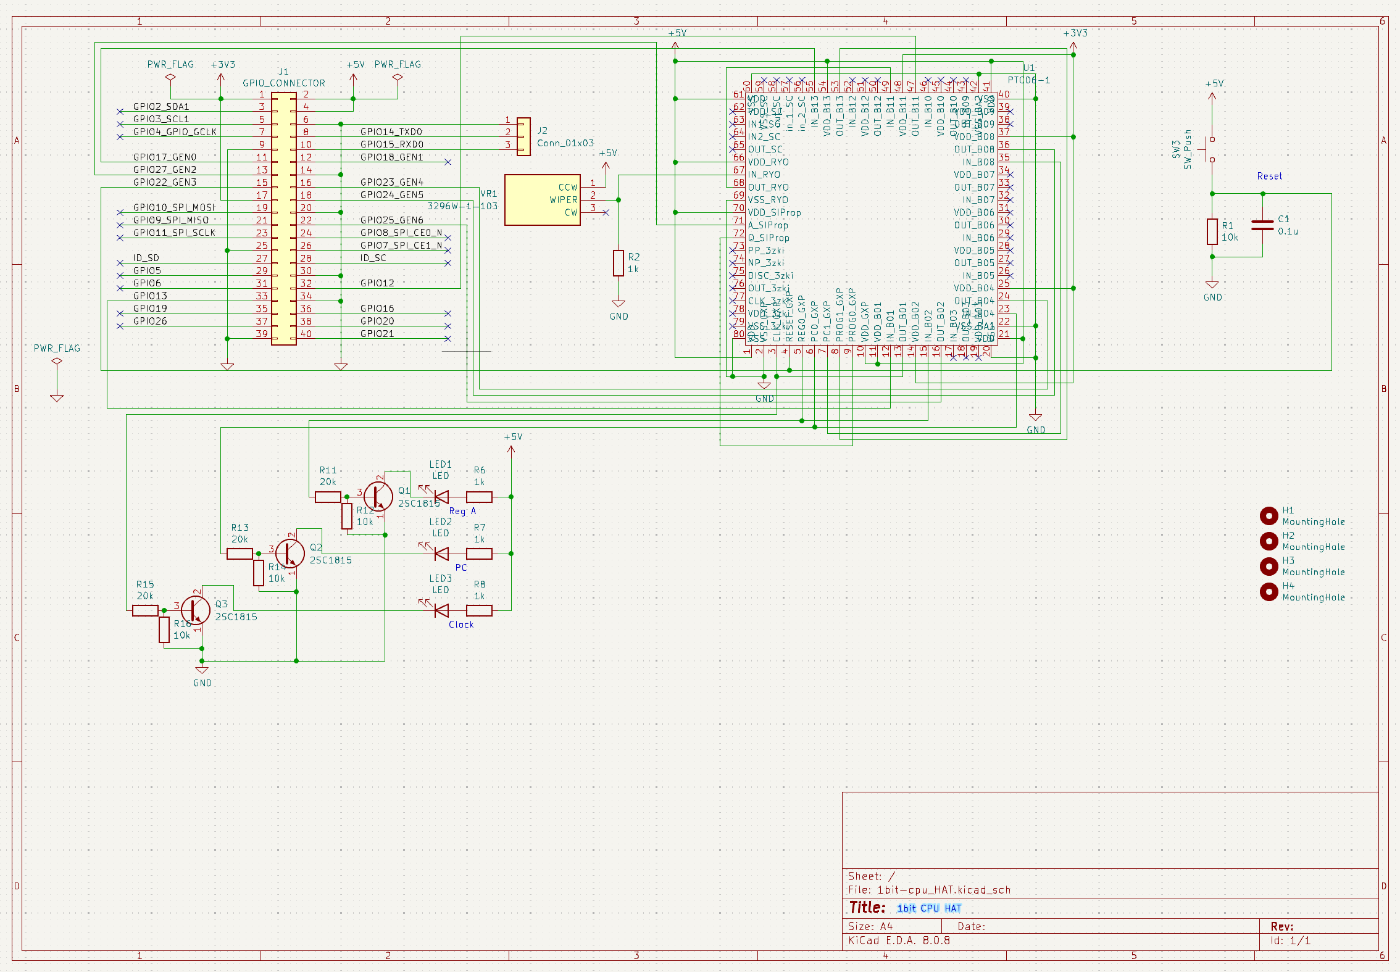
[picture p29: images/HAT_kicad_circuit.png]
 
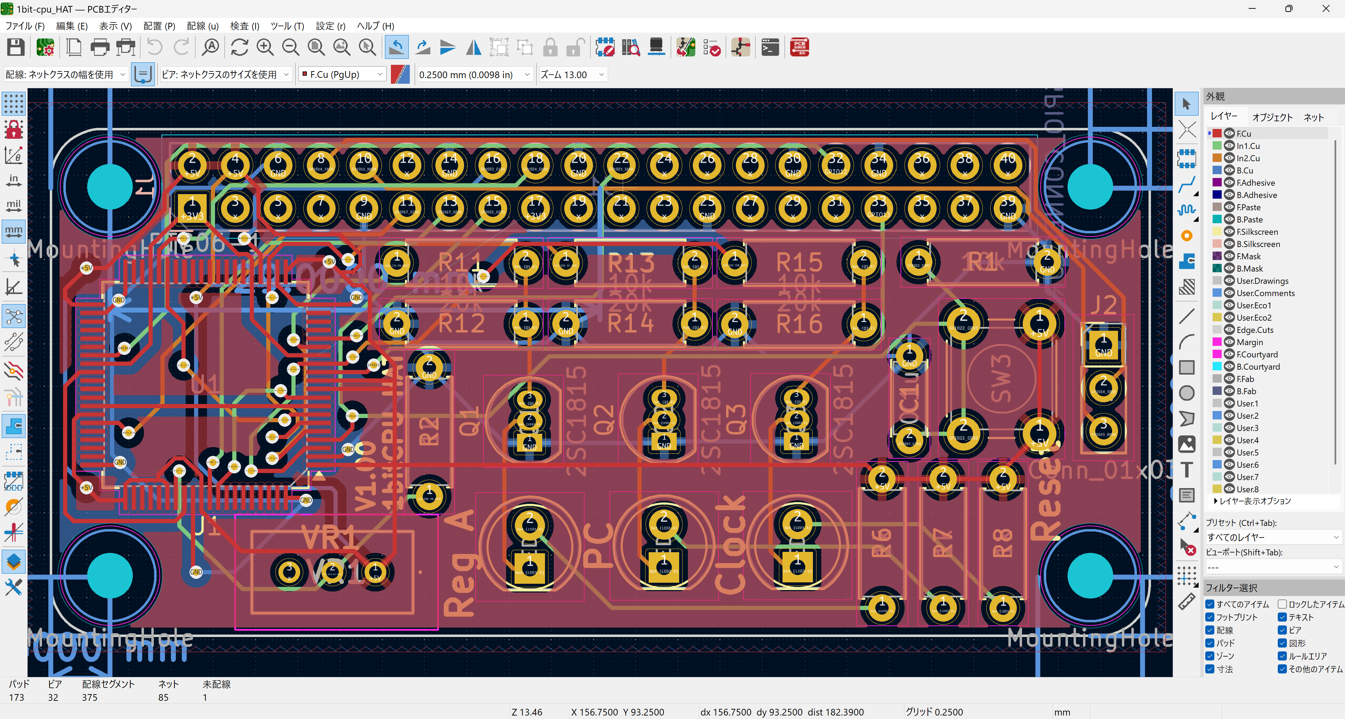
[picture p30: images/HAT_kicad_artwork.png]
 

- [本チップ用ラズパイHATディレクトリ：KiCADファイル](kicad/1bit-CPU_HAT)

## 実行用インタープリター
ラズパイ用のプログラム実行用のインタープリターの実装です。

- [本CPU用インタープリター](kicad/1bit-CPU_HAT/program/1bit-CPU_interpreter.py)

## 実際のボード
実際にラズパイZEROに装着した状態と動作状態。

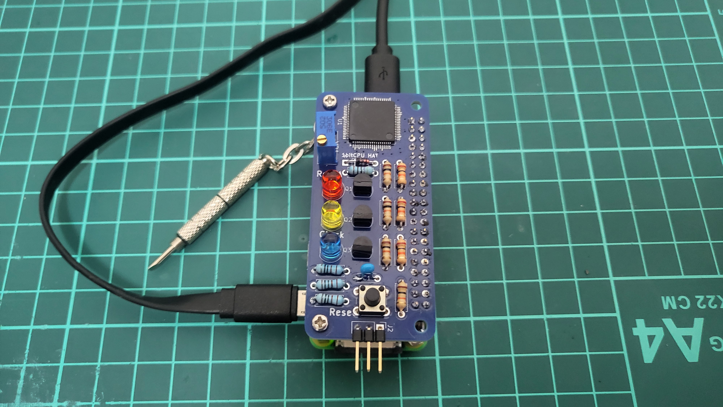
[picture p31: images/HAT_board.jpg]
ボード
 
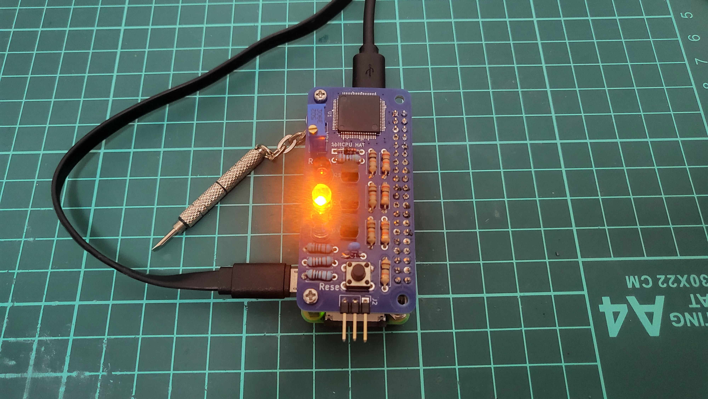
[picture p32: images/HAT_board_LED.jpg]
ボード：LED


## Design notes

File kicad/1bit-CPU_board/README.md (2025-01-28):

# 1bit-CPU
1bit CPU using 74HC series logic IC.

## Overview
This is a 1bit CPU KiCad file.
You can make a CPU using the 74HC series logic IC.

## Circuit Diagram


## Description
Left switch: Controls MUX to choose whether to update Reg A or PC  
Right switch: Controls second XOR operand or sets destination PC address

```
LR
00: MUX=0, RA=RA^0=RA,  PC=!PC
01: MUX=0, RA=RA^1=!RA, PC=!PC
10: MUX=1, RA=RA,       PC=0
11: MUX=1, RA=RA,       PC=1
```

In regular words:  
OFF, OFF will preserve the value of A and advance PC (0->1, 1->0)  
OFF, ON will invert the value of A (0->1, 1->0) and advance PC (0->1, 1->0)  
ON, OFF will preserve the value of A and set PC to 0  
ON, ON will preserve the value of A and set PC to 1  

```
01 23 | Function | Looped C equivalent | Description
----------------------------------------------------------------------------
00 00 | NOP, NOP | void; void;         | Do nothing
00 01 | NOP, INV | void; a=!a;         | Half frequency blink
00 10 | NOP, NOP | void; void;         | Do nothing
00 11 | NOP, HLT | void; while(1);     | Halt forever
01 00 | INV, NOP | a=!a; void;         | Half frequency blink
01 01 | INV, INV | a=!a; a=!a;         | Maximum frequency blink
01 10 | INV, NOP | a=!a; void;         | Half frequency blink
01 11 | INV, HLT | a=!a; while(1);     | Usually one state change, then halt
10 00 | HLT, NOP | while(1); void;     | Halt forever
10 01 | HLT, INV | while(1); a=!a;     | At most one state change, then halt
10 10 | HLT, NOP | while(1); void;     | Halt forever
10 11 | HLT, HLT | while(1); while(1); | Halt forever
11 00 | NOP, NOP | void; void;         | Do nothing
11 01 | NOP, INV | void; a=!a;         | Half frequency blink
11 10 | NOP, NOP | void; void;         | Do nothing
11 11 | NOP, HLT | void; while(1);     | Halt forever
```

## Video
1bit-CPU (https://www.youtube.com/watch?v=7_g6IDrb5PI)

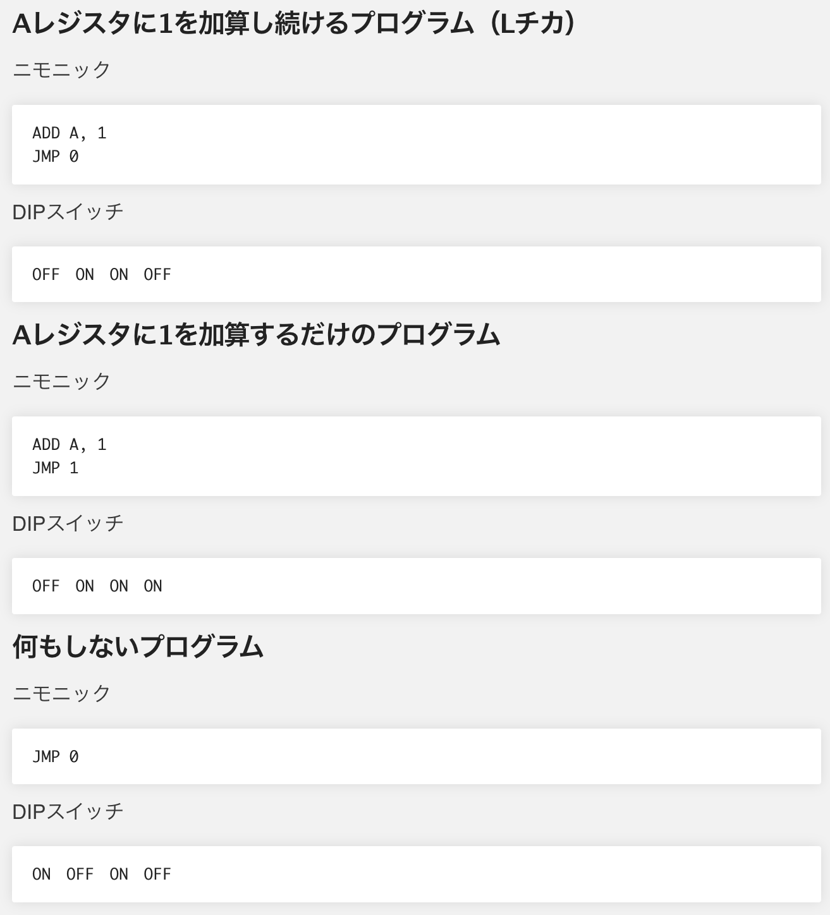
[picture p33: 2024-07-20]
images/1bit-CPU_prog.png

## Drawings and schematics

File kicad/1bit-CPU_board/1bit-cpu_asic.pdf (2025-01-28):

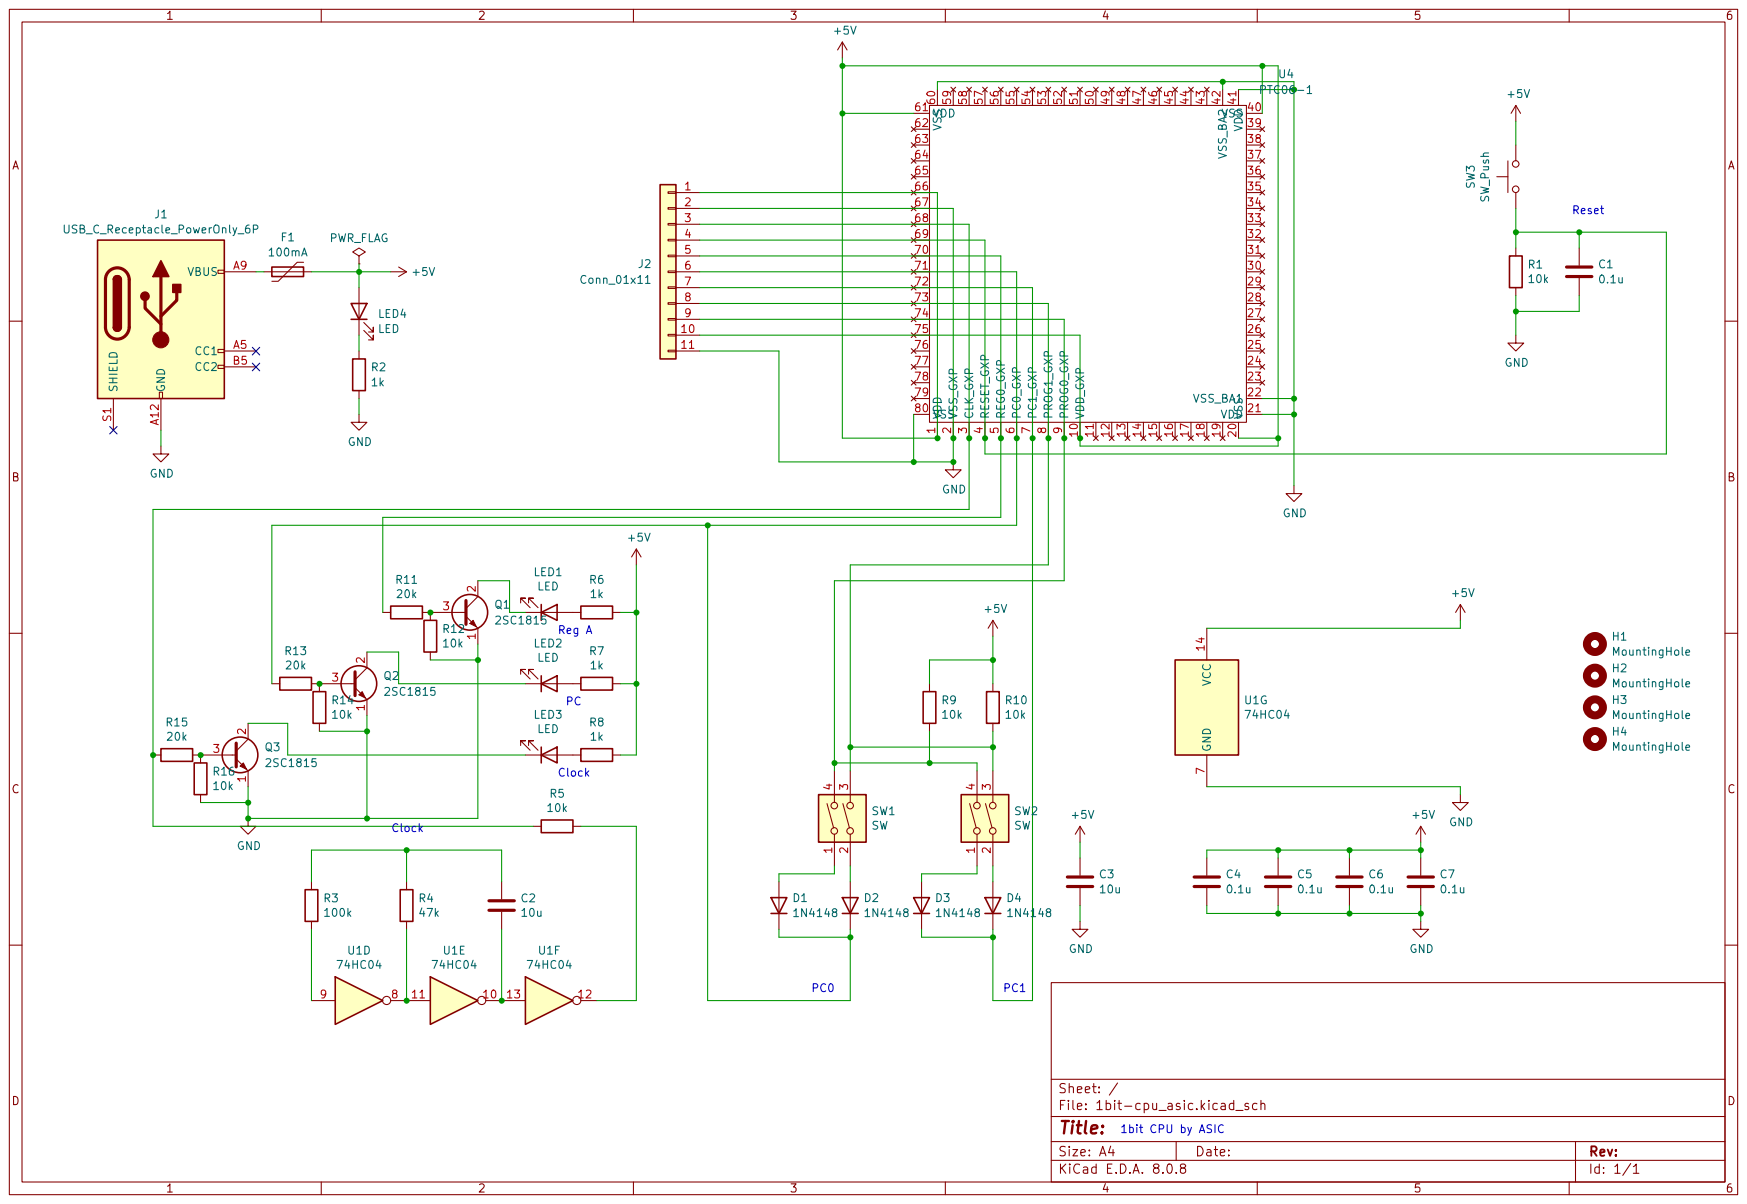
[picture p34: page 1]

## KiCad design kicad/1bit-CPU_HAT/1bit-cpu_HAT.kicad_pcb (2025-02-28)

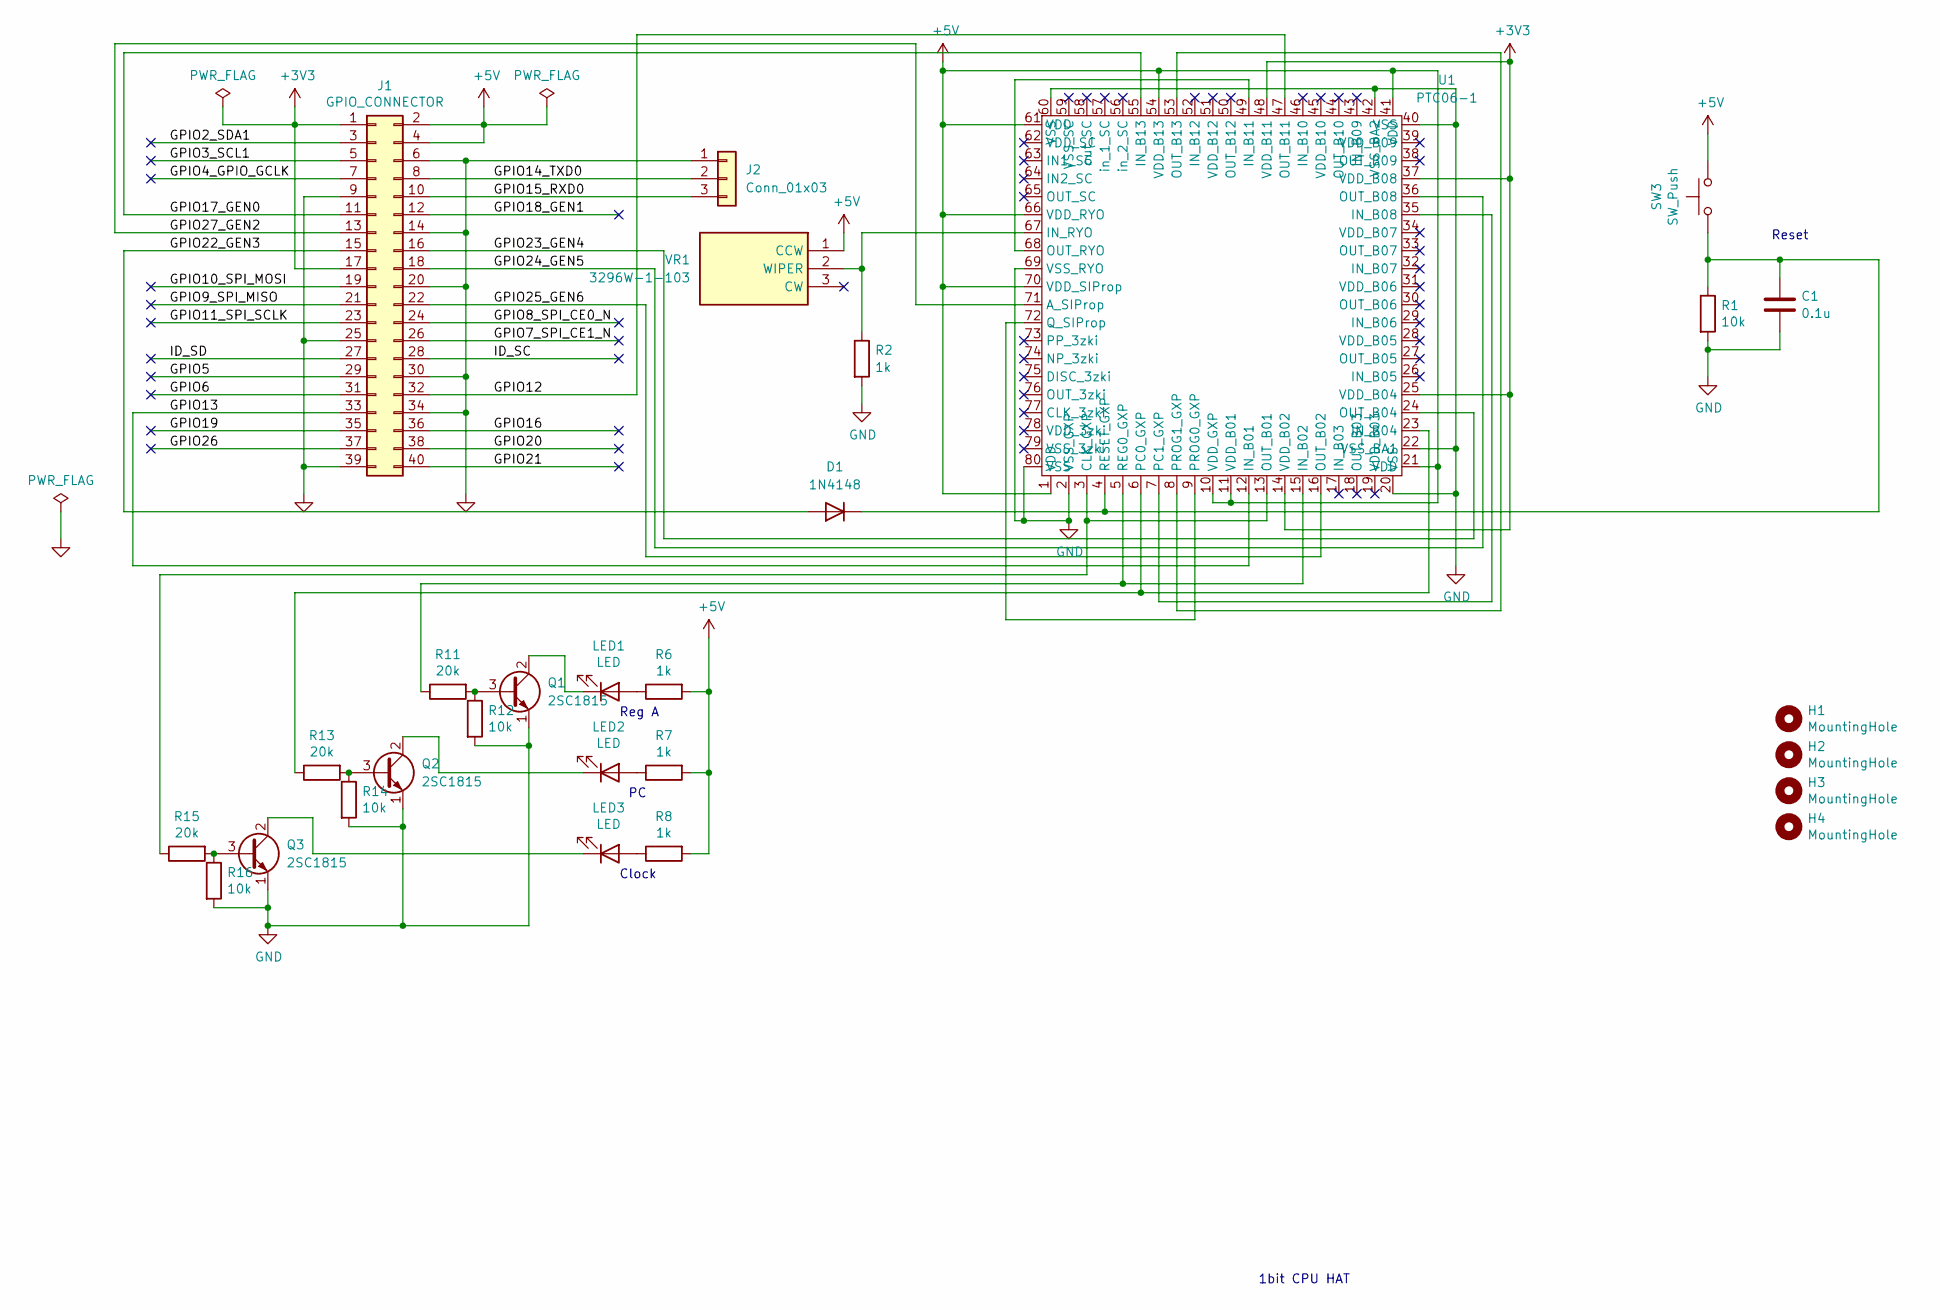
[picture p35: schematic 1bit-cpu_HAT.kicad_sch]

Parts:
C1: 0.1u; C_Disc_D4.3mm_W1.9mm_P5.00mm
D1: 1N4148; D_DO-35_SOD27_P7.62mm_Horizontal
H1, H2, H3, H4: MountingHole; MountingHole_2.7mm_M2.5_uHAT_RPi
J1: GPIO_CONNECTOR; PinSocket_2x20_P2.54mm_Vertical_Centered_Anchor
J2: Conn_01x03; PinHeader_1x03_P2.54mm_Vertical
LED1, LED2, LED3: LED; LED_D5.0mm
Q1, Q2, Q3: 2SC1815; TO-92_Inline
R1, R12, R14, R16: 10k; R_Axial_DIN0207_L6.3mm_D2.5mm_P7.62mm_Horizontal
R2, R6, R7, R8: 1k; R_Axial_DIN0207_L6.3mm_D2.5mm_P7.62mm_Horizontal
R11, R13, R15: 20k; R_Axial_DIN0207_L6.3mm_D2.5mm_P7.62mm_Horizontal
SW3: SW_Push; SW_PUSH_6mm
U1: PTC06-1; LQFP-80_12x12mm_P0.5mm
VR1: 3296W-1-103; 3296W1103; Mouser Part Number 652-3296W-1-103

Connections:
+3V3: J1.1, J1.17, U1.14 (VDD_B02), U1.25 (VDD_B04), U1.37 (VDD_B08), U1.48 (VDD_B11)
+5V: J1.2, J1.4, R6.2, R7.2, R8.2, SW3.1, U1.1 (VDD), U1.10 (VDD_GXP), U1.11 (VDD_B01), U1.21 (VDD), U1.41 (VDD), U1.54 (VDD_B13), U1.61 (VDD), U1.66 (VDD_RYO), U1.70 (VDD_SIProp), VR1.1 (CCW)
/GPIO2_SDA1: J1.3
/GPIO3_SCL1: J1.5
/GPIO4_GPIO_GCLK: J1.7
/GPIO5: J1.29
/GPIO6: J1.31
/GPIO7_SPI_CE1_N: J1.26
/GPIO8_SPI_CE0_N: J1.24
/GPIO9_SPI_MISO: J1.21
/GPIO10_SPI_MOSI: J1.19
/GPIO11_SPI_SCLK: J1.23
/GPIO12: J1.32, U1.47 (OUT_B11)
/GPIO13: J1.33, U1.12 (IN_B01)
/GPIO14_TXD0: J1.8, J2.2
/GPIO15_RXD0: J1.10, J2.3
/GPIO16: J1.36
/GPIO17_GEN0: J1.11, U1.55 (IN_B13)
/GPIO18_GEN1: J1.12
/GPIO19: J1.35
/GPIO20: J1.38
/GPIO21: J1.40
/GPIO22_GEN3: D1.2 (A), J1.15
/GPIO23_GEN4: J1.16, U1.24 (OUT_B04)
/GPIO24_GEN5: J1.18, U1.36 (OUT_B08)
/GPIO25_GEN6: J1.22, U1.16 (OUT_B02)
/GPIO26: J1.37
/GPIO27_GEN2: J1.13, U1.71 (A_SIProp)
/ID_SC: J1.28
/ID_SD: J1.27
GND: C1.1, J1.6, J1.9, J1.14, J1.20, J1.25, J1.30, J1.34, J1.39, J2.1, Q1.1 (E), Q2.1 (E), Q3.1 (E), R1.2, R2.2, R12.2, R14.2, R16.2, U1.2 (VSS_GXP), U1.20 (VSS), U1.22 (VSS_BA1), U1.40 (VSS), U1.42 (VSS_BA2), U1.60 (VSS), U1.69 (VSS_RYO), U1.80 (VSS)
unnamed: C1.2, D1.1 (K), R1.1, SW3.2, U1.4 (RESET_GXP)
unnamed: LED1.2 (A), R6.1
unnamed: LED1.1 (K), Q1.2 (C)
unnamed: LED2.2 (A), R7.1
unnamed: LED2.1 (K), Q2.2 (C)
unnamed: LED3.2 (A), R8.1
unnamed: LED3.1 (K), Q3.2 (C)
unnamed: Q1.3 (B), R11.2, R12.1
unnamed: Q2.3 (B), R13.2, R14.1
unnamed: Q3.3 (B), R15.2, R16.1
unnamed: R15.1, U1.3 (CLK_GXP), U1.13 (OUT_B01)
unnamed: R11.1, U1.5 (REG0_GXP), U1.15 (IN_B02)
unnamed: R13.1, U1.6 (PC0_GXP), U1.23 (IN_B04)
unnamed: U1.7 (PC1_GXP), U1.35 (IN_B08)
unnamed: U1.49 (IN_B11), U1.68 (OUT_RYO)
unnamed: R2.1, U1.67 (IN_RYO), VR1.2 (WIPER)
unnamed: U1.8 (PROG1_GXP), U1.53 (OUT_B13)
unnamed: U1.9 (PROG0_GXP), U1.72 (Q_SIProp)

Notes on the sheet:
Reg A
1bit CPU HAT
Clock
Reset

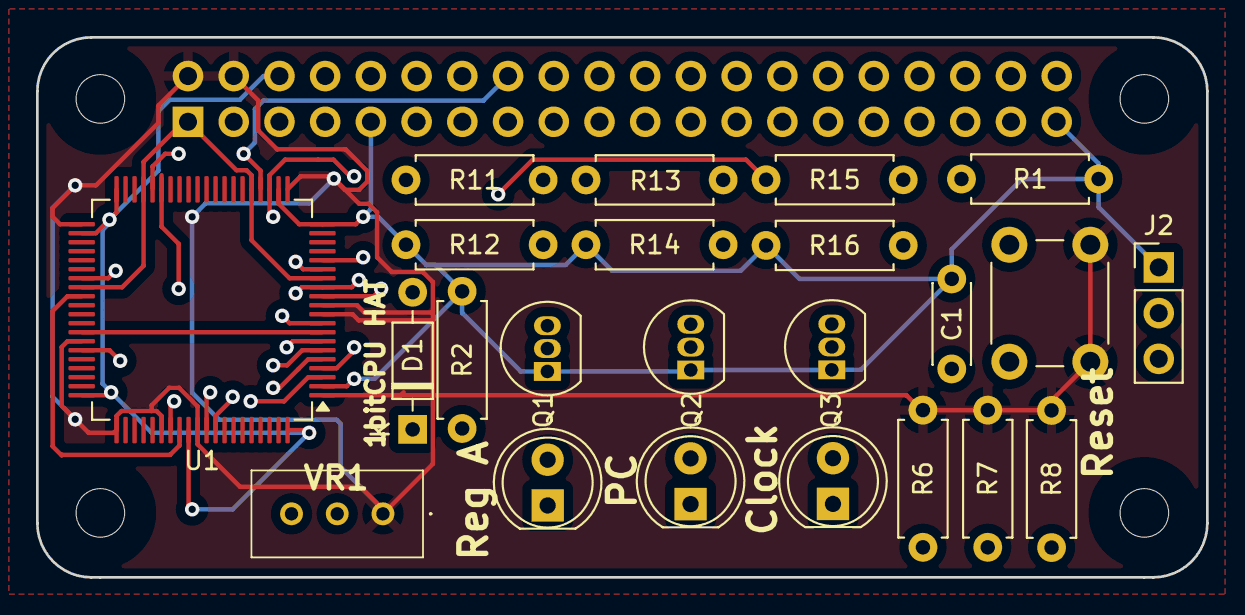
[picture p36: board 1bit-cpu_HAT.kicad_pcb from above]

Board: 4 copper layers, 65.0 x 30.0 mm, 28 parts (1 on the bottom side), 31 nets.

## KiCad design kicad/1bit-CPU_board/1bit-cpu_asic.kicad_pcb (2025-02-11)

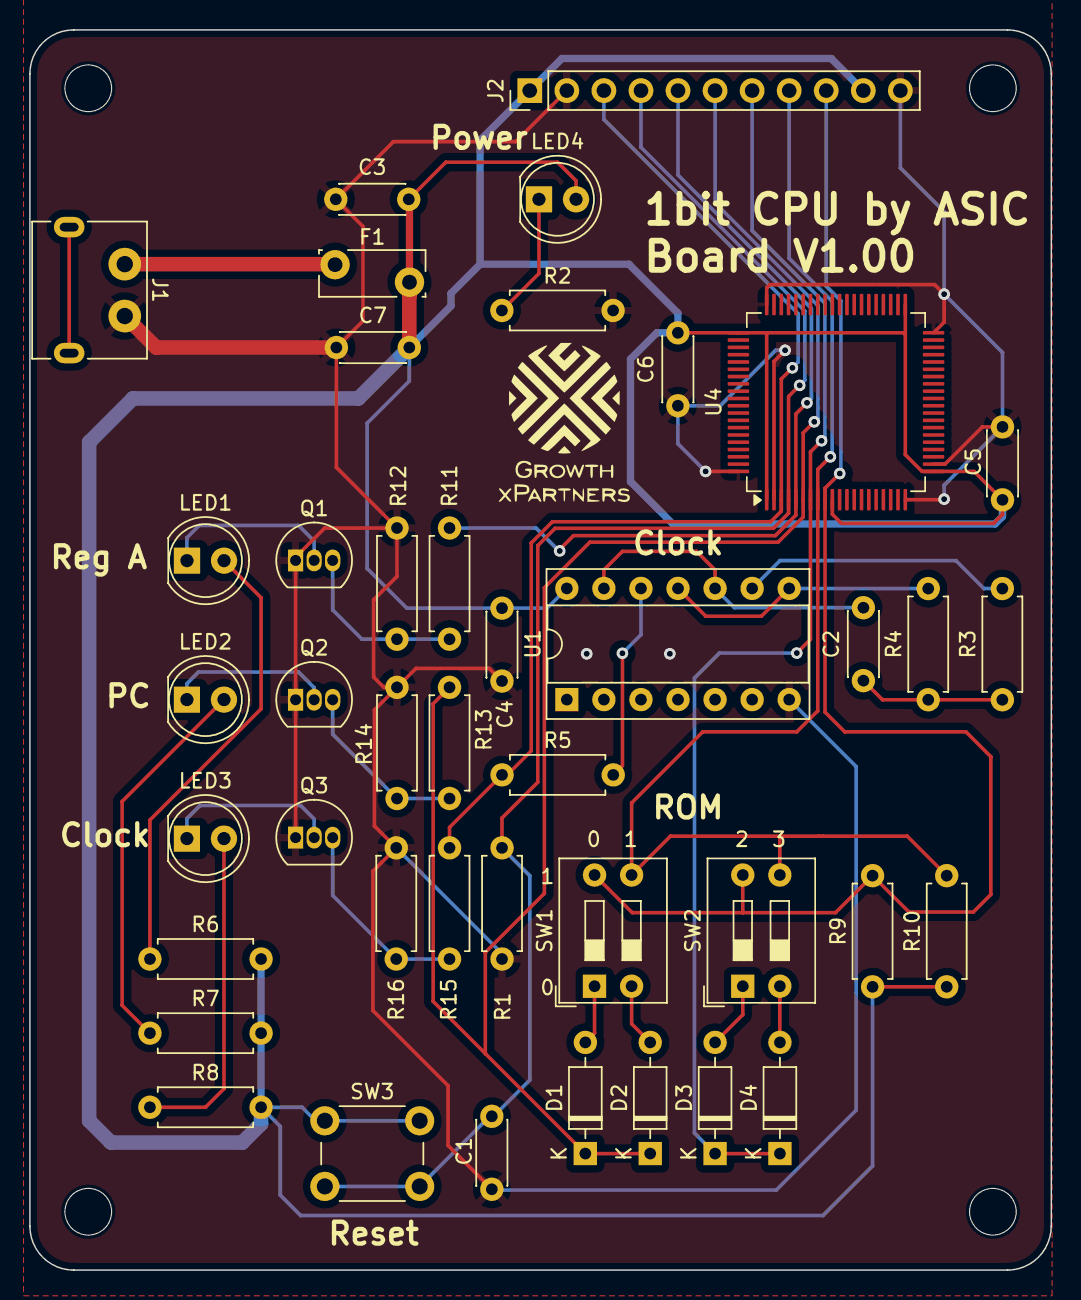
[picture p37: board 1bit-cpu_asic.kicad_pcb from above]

Board: 2 copper layers, 70.0 x 85.0 mm, 46 parts (0 on the bottom side), 29 nets.

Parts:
C1, C4, C5, C6, C7: 0.1u; C_Disc_D4.3mm_W1.9mm_P5.00mm
C2, C3: 10u; C_Disc_D4.3mm_W1.9mm_P5.00mm
D1, D2, D3, D4: 1N4148; D_DO-35_SOD27_P7.62mm_Horizontal
F1: 100mA; Fuse_Bourns_MF-RG300
H1, H2, H3, H4: MountingHole; MountingHole_3.2mm_M3
J1: USB_C_Receptacle_PowerOnly_6P; USB_C_PowerOnly
J2: Conn_01x11; PinHeader_1x11_P2.54mm_Vertical
LED1, LED2, LED3, LED4: LED; LED_D5.0mm
Q1, Q2, Q3: 2SC1815; TO-92_Inline
R1, R5, R9, R10, R12, R14, R16: 10k; R_Axial_DIN0207_L6.3mm_D2.5mm_P7.62mm_Horizontal
R2, R6, R7, R8: 1k; R_Axial_DIN0207_L6.3mm_D2.5mm_P7.62mm_Horizontal
R3: 100k; R_Axial_DIN0207_L6.3mm_D2.5mm_P7.62mm_Horizontal
R4: 47k; R_Axial_DIN0207_L6.3mm_D2.5mm_P7.62mm_Horizontal
R11, R13, R15: 20k; R_Axial_DIN0207_L6.3mm_D2.5mm_P7.62mm_Horizontal
SW1, SW2: SW; SW_DIP_SPSTx02_Slide_9.78x7.26mm_W7.62mm_P2.54mm
SW3: SW_Push; SW_PUSH_6mm
U1: 74HC04; DIP-14_W7.62mm_Socket
U4: PTC06-1; LQFP-80_12x12mm_P0.5mm

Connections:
+5V: C3.2, C4.2, C5.2, C6.2, C7.2, F1.2, J2.1, J2.10, LED4.2 (A), R6.2, R7.2, R8.2, R9.1, R10.1, SW3.1, U1.14 (VCC), U4.1 (VDD), U4.10 (VDD_GXP), U4.21 (VDD), U4.41 (VDD), U4.61 (VDD)
GND: C1.1, C3.1, C4.1, C5.1, C6.1, C7.1, J1.A12 (GND), J2.2, J2.11, Q1.1 (E), Q2.1 (E), Q3.1 (E), R1.2, R2.2, R12.2, R14.2, R16.2, U1.7 (GND), U4.2 (VSS_GXP), U4.20 (VSS), U4.22 (VSS_BA1), U4.40 (VSS), U4.42 (VSS_BA2), U4.60 (VSS), U4.80 (VSS)
unnamed: C2.1, R3.1, R4.1
unnamed: C2.2, U1.10, U1.13
unnamed: D1.2 (A), SW1.1
unnamed: D1.1 (K), D2.1 (K), J2.6, R13.1, U4.6 (PC0_GXP)
unnamed: D2.2 (A), SW1.2
unnamed: D3.2 (A), SW2.1
unnamed: D3.1 (K), D4.1 (K), J2.7, U4.7 (PC1_GXP)
unnamed: D4.2 (A), SW2.2
unnamed: F1.1, J1.A9 (VBUS)
unnamed: J2.3, R5.1, R15.1, U4.3 (CLK_GXP)
unnamed: C1.2, J2.4, R1.1, SW3.2, U4.4 (RESET_GXP)
unnamed: J2.5, R11.1, U4.5 (REG0_GXP)
unnamed: J2.8, R10.2, SW1.3, SW2.3, U4.8 (PROG1_GXP)
unnamed: J2.9, R9.2, SW1.4, SW2.4, U4.9 (PROG0_GXP)
unnamed: LED1.2 (A), R6.1
unnamed: LED1.1 (K), Q1.2 (C)
unnamed: LED2.2 (A), R7.1
unnamed: LED2.1 (K), Q2.2 (C)
unnamed: LED3.2 (A), R8.1
unnamed: LED3.1 (K), Q3.2 (C)
unnamed: LED4.1 (K), R2.1
unnamed: Q1.3 (B), R11.2, R12.1
unnamed: Q2.3 (B), R13.2, R14.1
unnamed: Q3.3 (B), R15.2, R16.1
unnamed: R3.2, U1.9
unnamed: R4.2, U1.8, U1.11
unnamed: R5.2, U1.12

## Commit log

2024-07-20 Add 1st commit.
    Add 1st commit.
    [1bit-CPU.sch, 1bit-CPU_1line.sch]
2024-07-21 Change Pin's VIA.
    Change Pin's VIA.
2024-07-21 Fix schematic.
    Fix schematic.
    [1bit-CPU.sch]
2024-07-25 Fix LVS model.
    Fix LVS model.
    [1bit-CPU.sch, 1bit-CPU_1line.sch]
2024-07-25 Fix schemtic.
    Fix schemtic.
    [1bit-CPU.sch]
2024-07-28 Add frame.
    Add frame.
2025-01-28 Add KiCAD data.
    Add KiCAD data.
    [1bit-cpu_asic-B_Cu.gbl, 1bit-cpu_asic-B_Mask.gbs, 1bit-cpu_asic-B_Paste.gbp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]
2025-02-11 Fix U4's 20&21 pin.
    Fix U4's 20&21 pin.
    [1bit-cpu_asic-B_Cu.gbl, 1bit-cpu_asic-B_Mask.gbs, 1bit-cpu_asic-B_Paste.gbp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]
2025-02-11 Fix U4's 40&41 pins.
    Fix U4's 40&41 pins.
    [1bit-cpu_asic-B_Cu.gbl, 1bit-cpu_asic-B_Mask.gbs, 1bit-cpu_asic-B_Paste.gbp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]
2025-02-11 Add board movie.
    Add board movie.
2025-02-28 Add 1bit-CPU HAT.
    Add 1bit-CPU HAT.
    [1bit-cpu_HAT-B_Cu.gbl, 1bit-cpu_HAT-B_Mask.gbs, 1bit-cpu_HAT-B_Paste.gbp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]
2025-03-04 Add Real HAT board.
    Add Real HAT board.
